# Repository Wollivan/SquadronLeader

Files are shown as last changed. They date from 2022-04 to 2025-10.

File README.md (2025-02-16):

###### visit [Squadron Leader Website](https://squadronleader.wollivan.dev)

###### visit [Squadron Leader subreddit](https://www.reddit.com/r/SquadronLeader/)

###### visit [Board Game Geek page](https://boardgamegeek.com/boardgame/362713/squadron-leader)

# Squadron Leader

#### The 3D printed, open source, aerial combat game you can fit in your pocket!

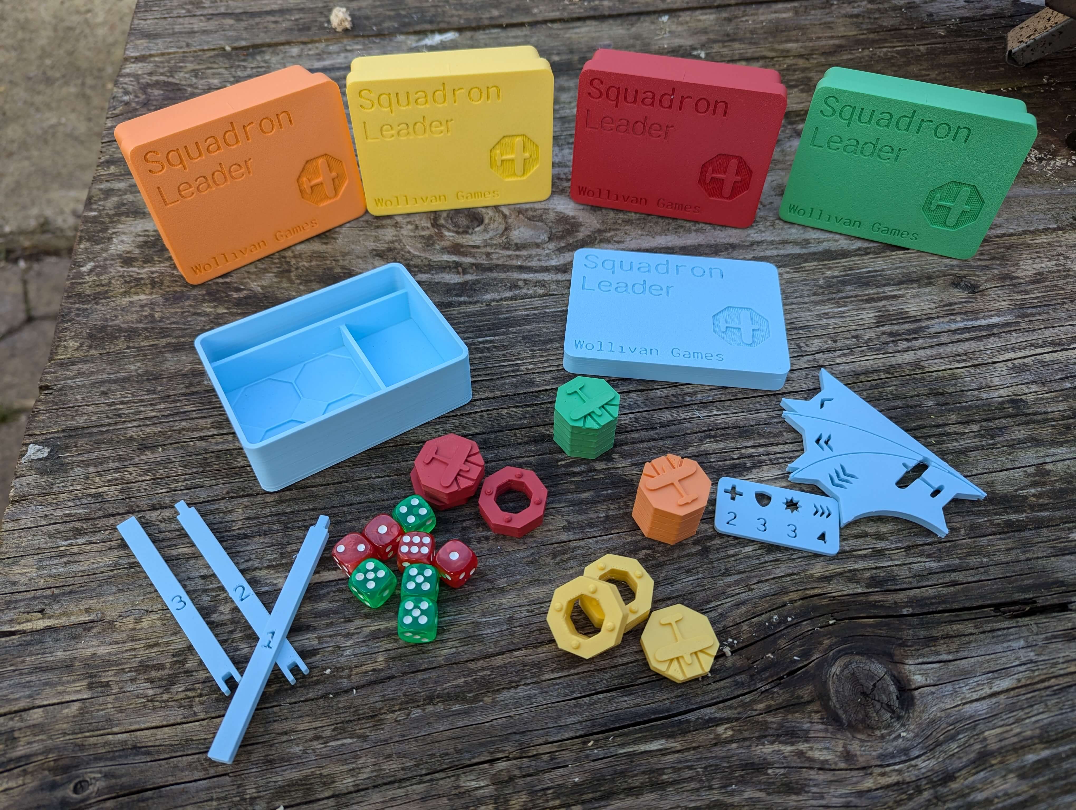
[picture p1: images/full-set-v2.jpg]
Squadron Leader Full Set


Squadron Leader is a fast-pace World War 1 (loosely) themed aerial combat game that is easy to learn and quick to play, with multifaceted strategy built-in that can be enjoyed by all ages!

The modular nature of the rules allows for players to customise their game and add entirely new layers of strategy.

We encourage the use of house rules, and if you think your rule improves the game, make a suggestion on <a href="https://github.com/Wollivan/SquadronLeader" target="_blank">GitHub</a>!

Tin art by Robert Linneman after the original Squadron Leader tobacco tin.

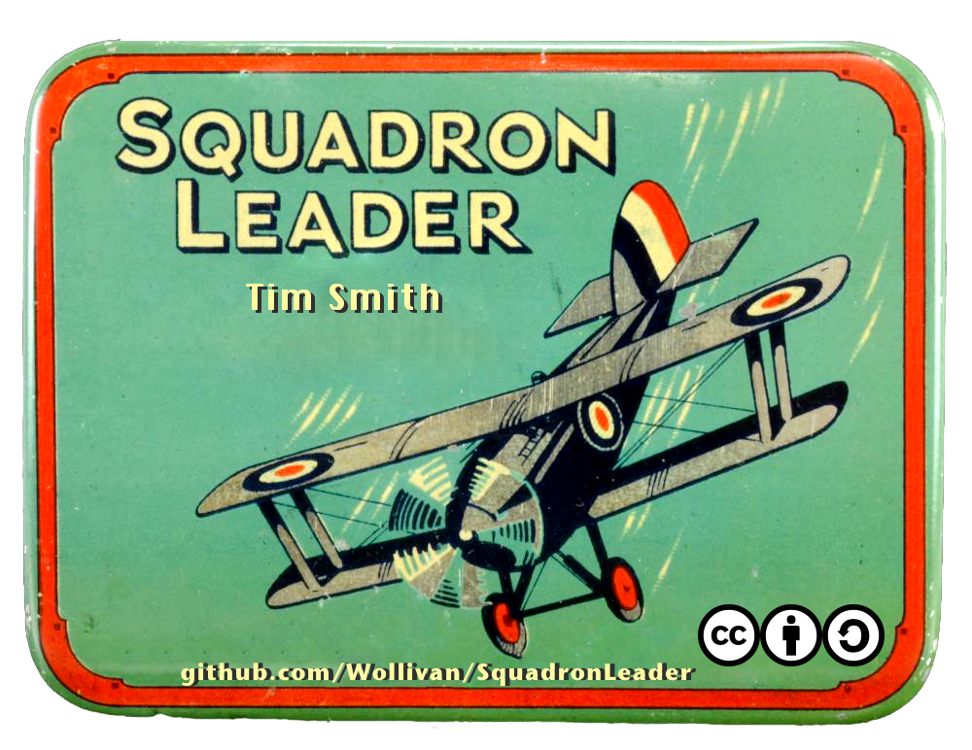
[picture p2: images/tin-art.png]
Squadron Leader Tin Art


### Learn the Game

- [How to Play](https://squadronleader.wollivan.dev/rules)
- [Advanced Manoeuvres](https://squadronleader.wollivan.dev/rules/advanced-manoeuvres)
- <a href="https://planes.wollivan.dev/" target="_blank">Plane Stat Tracker</a>

### Get Involved

- [Buy a copy](https://squadronleader.wollivan.dev/buy-a-copy)
- [Make your own copy](https://squadronleader.wollivan.dev/make-a-copy)
- [Make a change to the Project on GitHub](https://github.com/Wollivan/SquadronLeader)

**Note from the creator:**
This project is made possible only through the continued support of <a href="https://squadronleader.wollivan.dev/thanks" target="_blank">so many incredible people</a>, and for that I will be eternily grateful.
If you're viewing this on the website and want to see all the incredible work from the amazing people making this game better, check out the <a href="https://github.com/Wollivan/SquadronLeader/issues?q=is%3Aissue" target="_blank">issues</a>, <a href="https://github.com/Wollivan/SquadronLeader/pulls?q=is%3Apr" target="_blank">pull requests</a> and <a href="https://github.com/Wollivan/SquadronLeader/discussions" target="_blank">discussions</a> on GitHub.

## License

[Squadron Leader](https://github.com/Wollivan/SquadronLeader) by [Tim Smith](https://github.com/Wollivan) is licensed under [Attribution-ShareAlike 4.0 International](http://creativecommons.org/licenses/by-sa/4.0/?ref=chooser-v1)



CC BY-SA 4.0
Attribution-ShareAlike 4.0 International
This license requires that reusers give credit to the creator. It allows reusers to distribute, remix, adapt, and build upon the material in any medium or format, even for commercial purposes. If others remix, adapt, or build upon the material, they must license the modified material under identical terms.

BY: Credit must be given to the creator.

SA: Adaptations must be shared under the same terms.

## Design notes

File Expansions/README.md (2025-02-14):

# Expansions

There is a growing list of expansions that add additional pieces to the core game.

## X-Wing: The Miniatures Game Compatibility

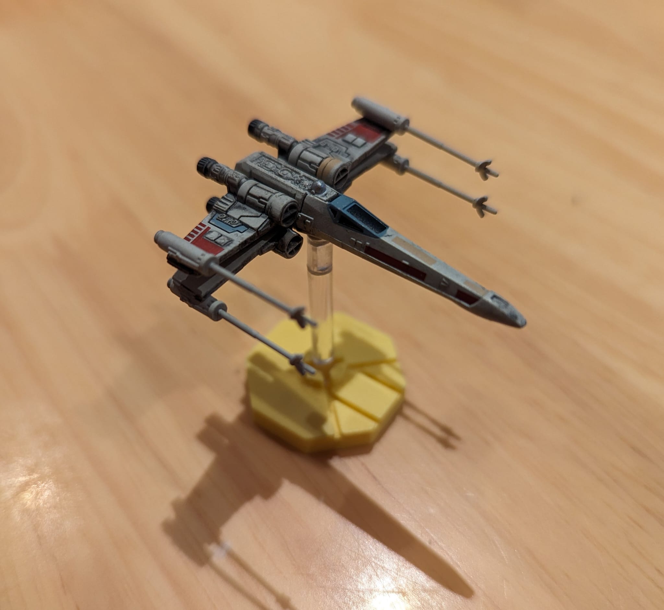
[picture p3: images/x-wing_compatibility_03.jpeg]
x-wing-assets


The force is strong with this one...

Use your X-Wing TMG collection to play Squadron Leader is a galaxy far far away!

<a href="https://squadronleader.wollivan.dev/expansions/x-wing-compatibility" class="button">Check it out!</a>

## Bomber & Balloons

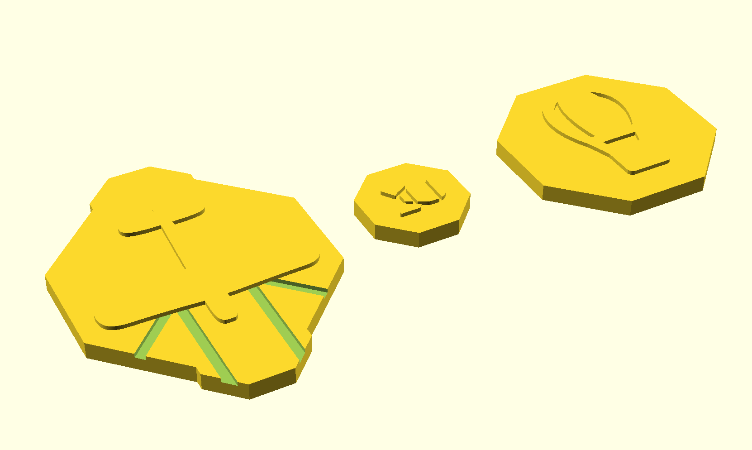
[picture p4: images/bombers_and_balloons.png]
bombers-and-balloons-assets


Bigger. Tougher. A fair bit slower.

<a href="https://squadronleader.wollivan.dev/expansions/bombers-balloons" class="button">Check it out!</a>

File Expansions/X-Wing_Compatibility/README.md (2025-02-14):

# X-Wing: The Miniatures Game Compatibility

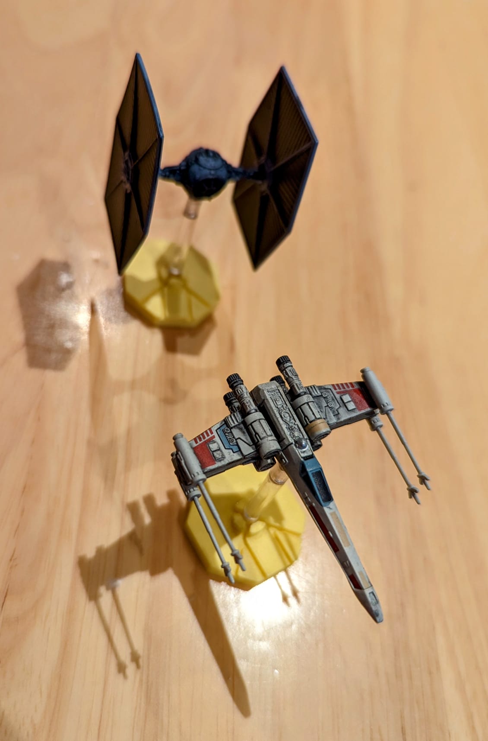
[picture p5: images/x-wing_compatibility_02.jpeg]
x-wing-assets


It's no secret that Squadron Leader was partially inspired by X-Wing TMG, so it stands to reason that there should be a way to use pieces from that amazing game to Sqquadron Leader.

Now you can with this new expansion!

There is a token for small bases using the 3mm peg, and large bases using the bomber token and space for the 6mm peg.

## Download Assets

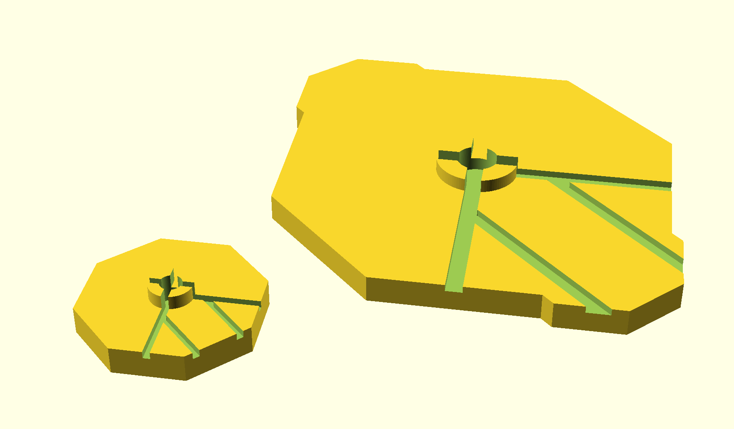
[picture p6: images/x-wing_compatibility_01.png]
x-wing-assets


Included:

- plane_xwing_tmg.stl
- plane_xwing_tmg_large.stl

<a href="https://github.com/Wollivan/SquadronLeader/tree/main/Expansions/X-Wing_Compatibility/STLs" class="button">Get the files</a>

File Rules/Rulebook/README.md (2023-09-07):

# Printable Rulebook for Squadron Leader

This page can be found at [sl-rulebook.wollivan.dev](https://sl-rulebook.wollivan.dev), or run locally.
It will give you a quick referece rules PDF to print out.

The reason there isn't a PDF saved here, is because the rules may change, and it saves whoever makes the change from having to regenerate the PDF.

Originally the rulebook site was run from a separate repo, but that felt wrong, so here it is to go with the rest of the Open Source goodness that is Squadron Leader.

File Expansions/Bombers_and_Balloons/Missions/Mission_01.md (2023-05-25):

# Mission 01 - The Errant Balloons

There are an unusual amount of Balloons in the area, I wonder if anyone is going to do anything about it!

## Game Piece Requirements

This misson requires:

- 3 Balloons
- 4 Planes

## Set up

One player will take all the Balloons and place them anywhere at least 1 range away from the edge of the play area.

Each player must place their tokens touching opposite sides of the play area to one another.
They start with 2 Planes each.

The player who placed the Balloons has an infinite supply of Planes. Every time one of their Planes are knocked out, wait 1 full round, then place the Plane back on the board anywhere along the edge the player originally started from.

## Objectives

The player who placed the Balloons must defend them at all costs!

The other player must destroy them... at any cost!

To destroy the Ballon, the player must attack them during the Attack Stage, and needs to make an attack with 2 hits.
A single hit on two consecutive turns won't cut it, it must be a double hit!

## Victory Requirements

The player who placed the Balloons wins if they destroy all enemy Planes.

The attacking player wins if they destroy all the Balloosn.

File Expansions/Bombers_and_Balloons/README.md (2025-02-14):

# Bombers & Balloons

bombers-and-balloons-assets

This expansion adds 2 new game pieces to the game, and you guessed them:

Bombers and Balloons!
(and a surprise third, the Bomb token)

## Bombers

Bombers use a larger token that can be found <a href="https://github.com/Wollivan/SquadronLeader/tree/main/Expansions/BombersAndBallons/STLs" target="_blank">here</a>. They use the same manoeuvre template as the other planes, making use of the extranious pieces at the front and back of the token.

Here are the special rules for the Bomber token:

- Instead of having the stats 4,3,3,2 to assign, they have 4,4,2,2
- Bombers are slower so their  must be 2
- Bombers may only spend 1 altitude when they dive
- The bomber can fire in a 360° arc if the enemy is within range 1-2 (forward arc is range 3)
- The bomber can "Drop Bombs"

### Dropping Bombs

At the end on their manoeuvre, the bomber may Drop a Bomb, by placing the bomb token at the other end of the template they just used for their manoeuvre.

Excluding the turn it was dropped, if any player is within range 1 of the bomb at the end the round, they roll 4  dice and takes 1 damage on all 4-6 results.

## Balloons

Balloons are a stationary object placed in the playing area before the game starts. Balloons are placed **before** planes.

During the game, if a player comes within range 1 of the balloon, that player immediatley rolls 4  dice and takes 1 damage on all 4-6 results.

It is up to the players to decide how many balloons each player may place before the game starts. They can be placed in any area the player chooses. Players take turns placing Balloons.

## Missions

There are some scenarios for players to use with their Bombers and balloons, and they can be found here:

<a href="https://squadronleader.wollivan.dev/expansions/bombers-balloons/mission-01.md" class="button">Mission 01 - The Errant Balloons</a>

<a href="https://squadronleader.wollivan.dev/expansions/bombers-balloons/mission-02.md" class="button">Mission 02 - The Bombers Escape</a>

## Cover

Bombers and Balloons both have one major thing in common... they are big!

If an attacker is shooting a target (any kind of target) they **roll 1 less dice** and **may not re-roll** any of their dice for this attack.

## Download Assets

Included:

- bomber.stl
- bomb.stl
- balloon.stl

<a href="https://github.com/Wollivan/SquadronLeader/tree/main/Expansions/Bombers_and_Balloons/STLs" class="button">Get the files</a>

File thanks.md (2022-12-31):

# Thank yous

First and most important thank you to <a href="https://twitter.com/HarryTheGM?t=-lbRdIOqqLyfzbsDPnInbA&s=09" target="_blank">Harry the GM</a> for inspiring me to make a game in the first place.

Playtesters. Without your help, this game would suck.

- Becky
- Bekah
- Ben
- Chris
- Dan
- Danny
- Harry
- John
- Josh
- Lydia
- Martin
- Matti
- Moses
- Patrick
- Priyatham

and a special thanks for their genius in coming up with a new barrel roll rule:

- Dylon
- Kirk
- Lila

a major thank you for their immediate help on release with getting the rules more readable, adding the Hex Grid rules and the d6 rules:

- Pelle

a thank you on the visual learners:

- Adam

for the awesome stat tracking designs:

- Greg

and for the important fix of making sure the game met Open Source requirements:

- avamk
- penyuan
- TechnologyClassroom

and for their awesome contributions to making an awesome printable box:

- Amnos
- Flo

and for STICKERS:

- mevdev

## Inspiration

This game was inspired by X-Wing TMG and Wings of War. The motivation for creating Squadron Leader was not as a replacement to either of these, rather as a alternative, when time, space and people who don't want to learn complex games are a factor when trying to get your gaming fix.

gameplay-gif

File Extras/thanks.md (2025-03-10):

# Thank yous

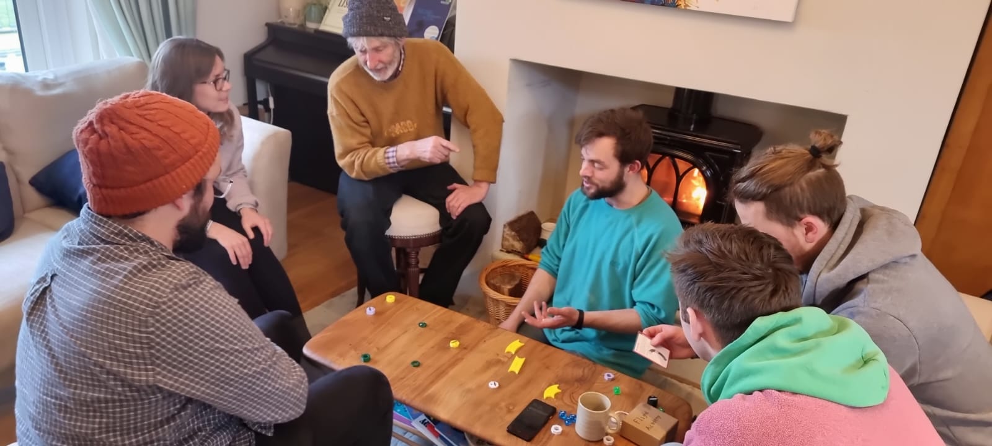
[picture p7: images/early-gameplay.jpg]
gameplay


First and most important thank you to <a href="https://twitter.com/HarryTheGM?t=-lbRdIOqqLyfzbsDPnInbA&s=09" target="_blank">Harry the GM</a> for inspiring me to make a game in the first place.

Playtesters. Without your help, this game would suck.

- Becky
- Bekah
- Ben
- Chris
- Dan
- Danny
- Harry
- John
- Josh
- Lydia
- Martin
- Matti
- Moses
- Patrick
- Priyatham

and a special thanks for their genius in coming up with the original barrel roll rule:

- Dylon
- Kirk
- Lila

a major thank you for their immediate help on release with getting the rules more readable, adding the Hex Grid rules and the d6 rules:

- Pelle

a thank you on the visual learners:

- Adam

for the awesome stat tracking designs, still available within the v1 folders:

- Greg

and for the important fix of making sure the game met Open Source requirements:

- avamk
- penyuan
- TechnologyClassroom

and for their awesome contributions to making an awesome printable box:

- Amnos
- Flo

and for STICKERS:

- mevdev

and for the Push the Envelope rules:

- asmialek

and for teaching me that all these special manoeuvres have names

- Ben

and for finding Split S so that what the rules do in game match what real life planes can do!

- Josh

and for a lot of inspiration on the Bimber expansion

- u/ReasonablyCreamy

## Future features

- Coop objectives & campaigns
- Large scale battle rules (10+ ships per team)
- Assets & instructions for playmats
- Printable assets for 3D models on blank bases
- More accessible components for less able players

## Inspiration

This game was inspired by X-Wing TMG and Wings of War. The motivation for creating Squadron Leader was not as a replacement to either of these, rather as a alternative, when time, space and people who don't want to learn complex games are a factor when trying to get your gaming fix.

How it started:

unboxing

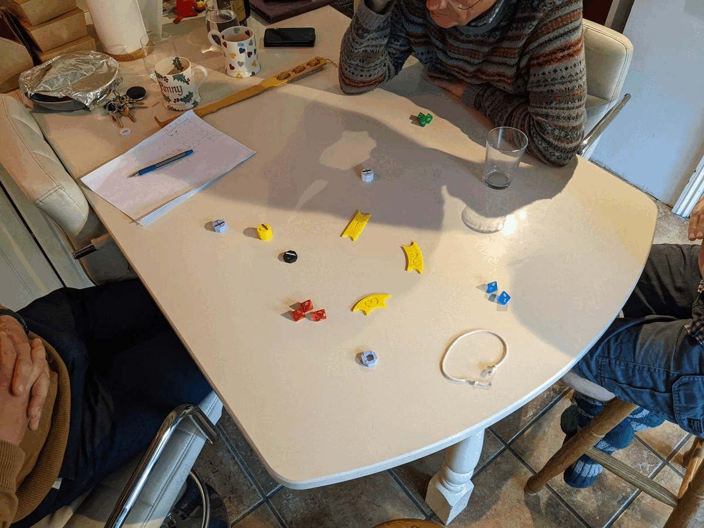
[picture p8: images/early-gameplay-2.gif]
gameplay-gif


How it's going:

unboxing

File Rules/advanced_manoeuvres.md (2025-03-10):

# Advanced Manoeuvres

For players already familiar with the core rules or those seeking to become world-famous fighter pilots, the following advanced manoeuvres provide additional tactical options:

**Note:** Manoeuvres that cost altitude cannot be performed in the same round that the player has gained altitude.

## Barrel Roll

This manoeuvre seperates the timid from the bold!

**Cost:** This is the only manoeuvre you can do this round

**Action:** Perfom a 3 cost manoeuvre but don't rotate your token afterwards

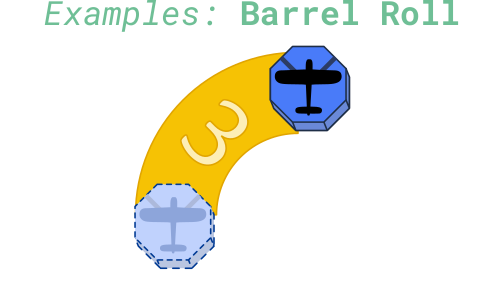
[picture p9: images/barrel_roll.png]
barrel_roll_diagram


## Dive Bomb

Reward hyper-aggresive tactics with this risky manoeuvre!

**Requirement:** Perform an attack against a plane within range 1 that has less altitude

**Cost:** Reduce altitude to match defender

**Action:** Roll a d6:

- Result of 3-6: Deal one damage.
- Result of 1-2: Take one damage.

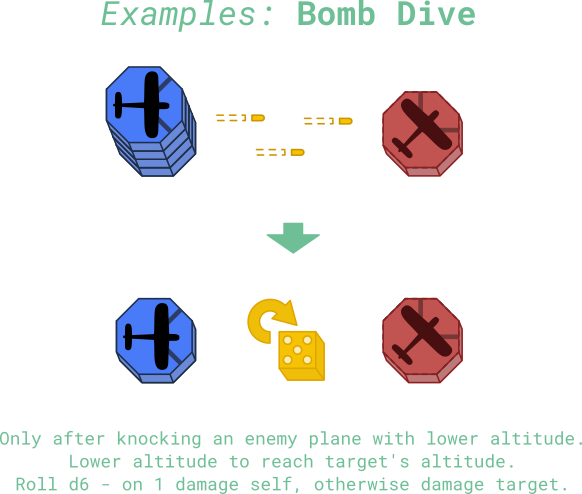
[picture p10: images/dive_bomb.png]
dive_bomb_diagram


Not to be confused with Divebomb, the homicidal Decepticon.

## Immelmann

Few pilots ever pull this manoeuvre off.

**Requirement:** Eliminate opponent while you have no altitude tokens

**Action:** Gain 4 altitude, perform a straight manoeuvre and rotate plane 180°

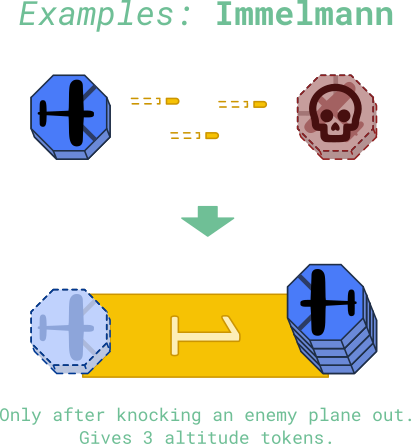
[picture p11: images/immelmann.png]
immelmann_diagram


## Push the Envelope

This manoeuvre rewards daring pilots who are willing to test the limits of the aircraft by going faster and higher than it should be possible!

A player may push the envelope during the manoeuvre stage and roll a d6:

**Requirement:** Execute during Manoeuvre stage, once per round

**Action:** Roll a d6:

- Result of 5-6: Gain 1  this round OR 1 extra altitude.
- Result of 1-4: Take one damage.

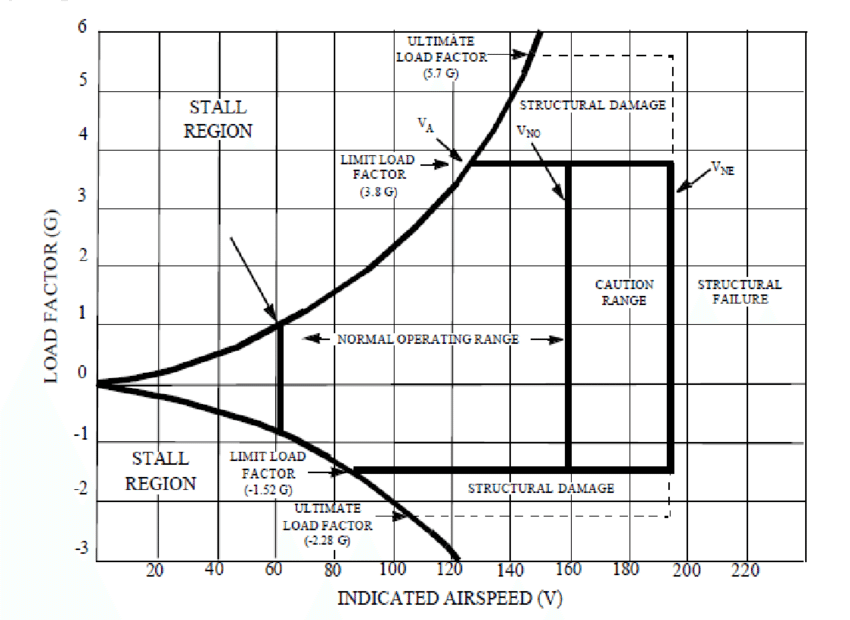
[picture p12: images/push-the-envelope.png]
push-the-envelope


### More Info

All the manoeuvres are informed by real life actual plane stuff!

- [Barrel Roll](https://en.wikipedia.org/wiki/Barrel_roll): "A barrel roll is an aerial manoeuvre in which an airplane makes a complete rotation on both its longitudinal and lateral axes, causing it to follow a helical path, approximately maintaining its original direction."

- [Dive Bomb](https://en.wikipedia.org/wiki/Dive_bomber): "A dive bomber is a bomber aircraft that dives directly at its targets in order to provide greater accuracy for the bomb it drops. Diving towards the target simplifies the bomb's trajectory and allows the pilot to keep visual contact throughout the bomb run."

- [Immelmann](https://en.m.wikipedia.org/wiki/Immelmann_turn): "In modern aerobatics, an Immelmann turn (also known as a roll-off-the-top, or simply an Immelmann) is an aerobatic manoeuvre that results in level flight in the opposite direction at a higher altitude."

- [Push the Envelope](https://en.wikipedia.org/wiki/Flight_envelope#%22Pushing_the_envelope%22): "The flight envelope is a graph visualizing the capabilities of the aircraft in terms of min-max speeds and the altitude at which it can safely fly. The envelope itself is of course defined by various parameters and there is absolutely no way of simulating that in a board game. But, there is a term "Pushing the envelope", which means that the pilot tries to go over the speed or altitude defined by the flight envelope while risking the integrity of the aircraft (or causing the plane to stall)."

- [Split S](https://en.m.wikipedia.org/wiki/Split_S): "To execute a split S, the pilot half-rolls their aircraft inverted and executes a descending half-loop, resulting in level flight in the opposite direction at a lower altitude."

### Printable Rulebook

No not that sort of printing, _actual_ printing with paper and everything!

If you want a quick reference to the rules that fits in the printable (3D this time) box, then you can donwload the PDF from [here](https://sl-rulebook.wollivan.dev), or go to [the folder that website comes from](https://github.com/Wollivan/SquadronLeader/tree/main/Rules/Rulebook) if you want to make a change.

This bifold book contains the basic rules and a quick reference to the advanced manoeuvres.

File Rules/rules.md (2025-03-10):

# Rules

**Objective:** Be the last plane in the air by reducing your opponents' Health to zero.

## Setup:

Each player needs:

- 1 plane token
- 4 altitude tokens

Shared items:

- 1 move template
- 1 range ruler
- 4 Red d6 for Attack dice
- 4 Green d6 for Defense dice

### Playing Area:

The playing area can be any size, typically the entire table. For a consistent size, try 3 lengths of the range ruler.

### Starting Assignments:

At the beginning of the game, each player assigns values from 4, 3, 3, 2 to the following attributes:

 - Health

 - Defense

 - Attack

 - Manoeuvrability

Suggested starting setup for new players:

 - 3

 - 3

 - 2

 - 4

Use the <a href="https://planes.wollivan.dev/" target="_blank">online stat tracker</a>, or print the v1 stat wheels (requires a v1 box).

### Determining First Player:

The player who last saw a plane in real life goes first.

### Placing the Planes:

Each player places their plane on the playing area in turn. The plane should be placed within range 1 of the edge of the playing area, and no closer than the range ruler's length to another player.

### Game Rounds:

Each round consists of two stages: the Manoeuvre Stage and the Attack Stage.

The player who starts the round moves and attacks first. In the next round, the player to their left will start the round.

## Manoeuvre Stage:

- To move, place the manoeuvre template at the front of the plane token and move the plane to the other end of the template.
- Players can use manoeuvre templates up to the value of their  score. For example, a player with  4 can execute 2 straight manoeuvres and 1 bank manoeuvre (1 + 1 + 2).
- Each player must complete at least one manoeuvre each round; otherwise, their plane will stall and plummet to the ground.
- If any part of a plane token goes off the board at the end of a manoeuvre, that plane is destroyed.

### Altitude:

Take advantage of the sky's vastness!

- At the start of the game, each player begins with 0 altitude tokens.
- Once per round during their manoeuvre stage, a player may spend 1  to Climb and add 1 altitude token beneath their plane.
- Players can gain a maximum of 1 altitude per round.
- If a player hasn't Climbed this round, they may Dive by removing any number of altitude tokens to gain an equal amount of  this round.
- The maximum allowed altitude is 4.

### Split S

This manoeuvre prevents a pilot from being stuck when they are being tailed by an opponent.

**Cost:** 4 altitude
**Action:** Turn 180° after manoeuvre

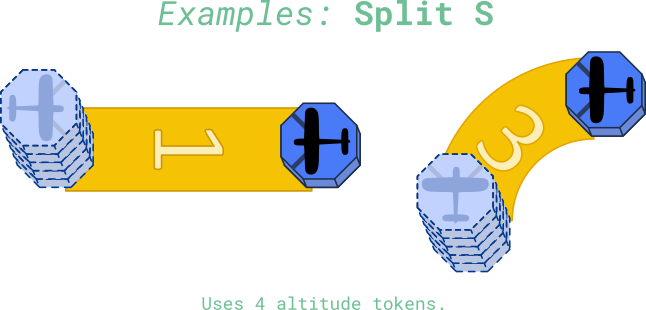
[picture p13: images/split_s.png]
split_s_diagram


Note: You can't Split S on the same turn as gaining altitude.

## Attack Stage:

- The attacker declares which enemy plane they will attack.
- A player can only attack if the enemy plane is within range.
  - Use the range ruler to ensure both planes are within the designated distance from each other.
- The defender must also be within the attacker's firing arc, indicated by the 90° lines on the front of the token.
- The attacking player rolls a number of  dice equal to their Attack value.
- The defending player rolls a number of  dice equal to their Defense value.
- Each value of 4-6 rolled on the  dice counts as a **hit** and deals 1 damage.
- Each value of 4-6 rolled on the  dice counts as a **dodge** and cancels out a hit.
- Rolling a 6 results in a **critical hit** or a **vital dodge**, counting as 2 hits or dodges respectively.
- The defender loses  equal to the uncanceled hits.

Example of the firing arc:
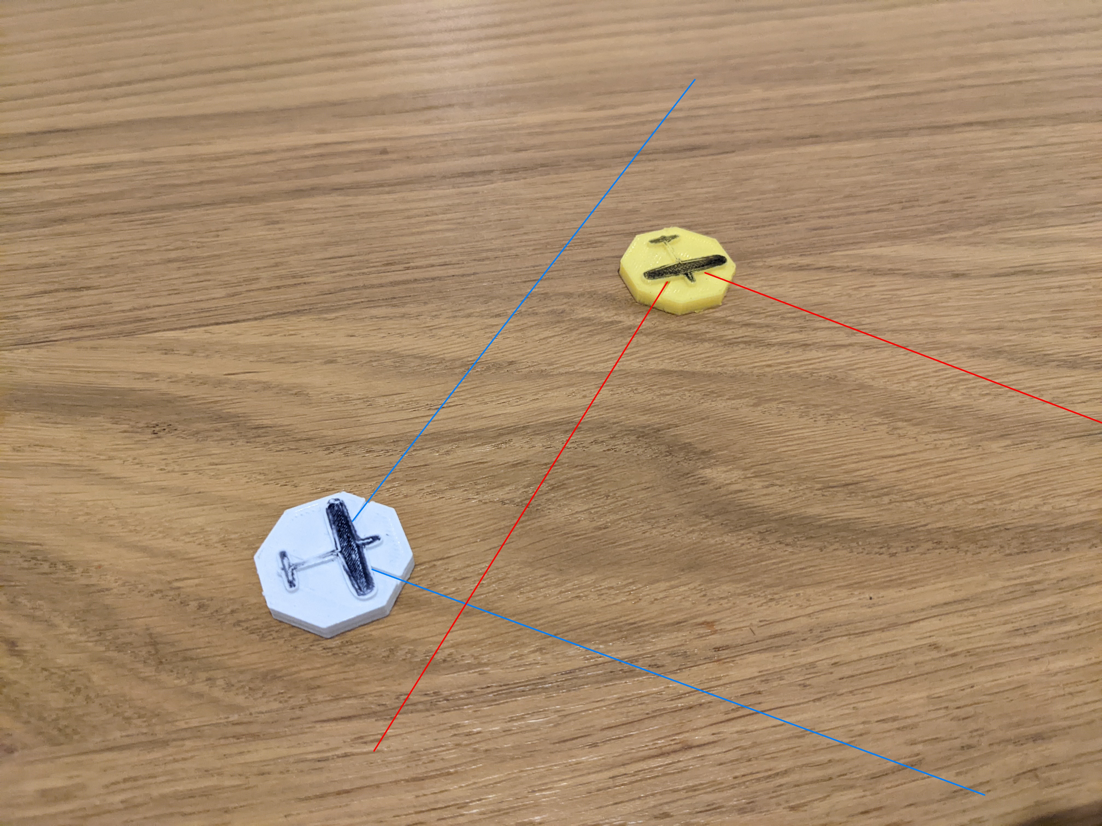
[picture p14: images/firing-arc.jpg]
firing-arc


### Attack/Defense Bonuses:

Bonuses allow rerolling of dice. The number of dice rolled is determined by the Attack/Defense stats.

- The defender may reroll 1 die if they are within range 3 of the attacker.
- The attacker may reroll 1 die if the defender is within range 1.
- If the defender is within the attacker's forward firing guides, the attacker may reroll 1 die.
- An attacker or defender with higher altitude may reroll 1 die.
- When you destroy an enemy plane, you may reroll 1 die during your next attack.

## Next Round:

After the last player who can attack finishes their turn, a new round begins with the next starting player.

### Advanced Manoeuvres:

Explore the [advanced manoeuvres](https://squadronleader.wollivan.dev/rules/advanced-manoeuvres) and test your skills to rule the air!

### Printable Rulebook

No not that sort of printing, _actual_ printing with paper and everything!

If you want a quick reference to the rules that fits in the printable (3D this time) box, then you can donwload the PDF from [here](https://sl-rulebook.wollivan.dev), or go to [the folder that website comes from](https://github.com/Wollivan/SquadronLeader/tree/main/Rules/Rulebook) if you want to make a change.

This bifold book contains the basic rules and a quick reference to the advanced manoeuvres.

**Enough chatter, it's time to take to the skies!**

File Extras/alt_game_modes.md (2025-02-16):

# Alternative Game modes

## Team game

You can change the feel of the game greatly by flying with a wingman. The strategy of how you fly together is totally up to you. Here are the additional rules for playing in teams:

- Teammates should sit next to one another.
- The playing order is determined by teams, rather than players, so within your team you decide who moves first, and once the entire team has moved, the other team goes. This is the same principle for attacking.

## Quick game

There are a few ways to make the game shorter:

- Have everyone start with a max of 2 Health.
- Designate a smaller playing area.
- Allow players to gain more than 1 altitude per round.

Feel free to experiment with the starting numbers, the original 4,3,3,2 is a guideline for balanced games, so going higher will change the game. As long as each player has the same choices it SHOULD be fair.

## Hex Grid Mode (for players without a 3D printer)

The game can be played on a hex grid. That removes the need for manoeuvre templates and range rulers. All rules are the same as without a grid, except for what is described in this section.

Any battlemat with a hex grid can be used. Planes set up in hexes along each player's edge of the mat. There can only ever be one plane per hex, and planes can never end a manoeuvre in the same hex as another plane. A plane always face one of the six sides of its hex.

Instead of using the manoeuvre templates there are three possible manoeuvres on a hex grid that are used instead:

- 1 (Cost 1) Move 2 hexes forward.
- 2 (Cost 2) Move 1 hex forward, then turn left or right 60 degrees, then move 1 hex forward in the new direction.
- 3 (Cost 3) Turn 60 degrees, then move 1 hex forward, then turn another 60 degrees in the same direction as the first turn

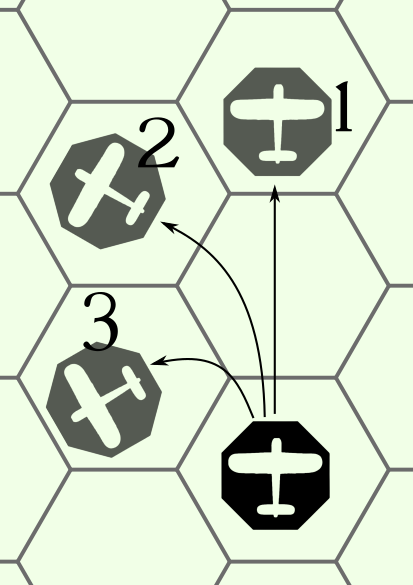
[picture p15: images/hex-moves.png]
hex_moves


Attacks are up to range 3. Count range in hexes, not including the hex occupied by the attacking plane, but including the attacked plane. The firing arc of a plane is a cone in front of it, starting with the single hex in front, then the 3 hexes in front of that, then the 5 beyond those.

The hexes immediately in front of the firing plane corresponds to the closest section of the range ruler for the purpose of attack bonuses. Hexes at range 3 corresponds to the furthest section of the range ruler.

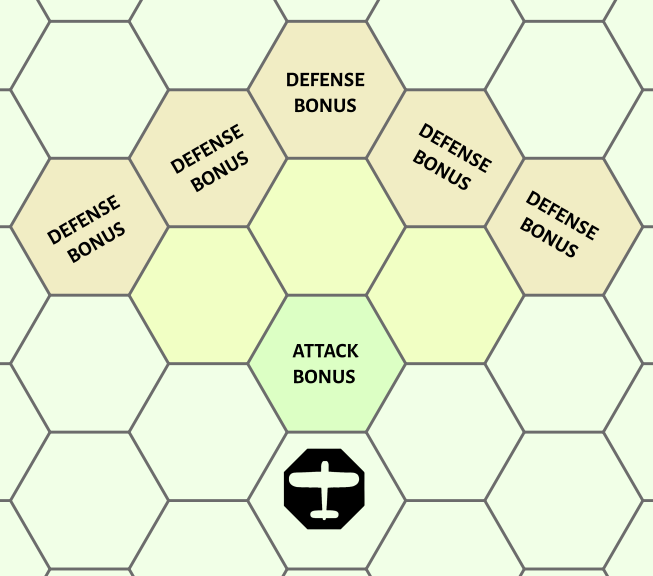
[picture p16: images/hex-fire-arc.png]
hex_fire_arc


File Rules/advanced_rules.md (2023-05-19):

# Advanced Rules

These rules are for players already familiar with the core rules, or those who want to dive right in and become world famous fighter pilots!

## Split S

This rule prevents a pilot from being stuck when they are being tailed by an opponent.

- The Split S costs 4 altitude to execute.
- Turn the plane token 180° at the end of the manoeuvre.
- Players cannot perform a Split S and gain altitude in the same round.

split-s

You can read more about the Split S manoeuvre here:

<a href="https://en.m.wikipedia.org/wiki/Split_S" target="_blank" class="button">Split S Wiki</a>

Here is an excerpt:

"To execute a split S, the pilot half-rolls their aircraft inverted and executes a descending half-loop, resulting in level flight in the opposite direction at a lower altitude."

## Immelmann

This rule rewards aggressive tactics.

- This free manoeuvre that can only be performed immediatley after reducing another opponent's Health to 0.
- Do the following actions in order:
  - Gain 3 altitude tokens
  - Execute a straight
  - Turn your plane 180° (facing the opposite direction to the way they were).

immelmann_with_text

You can read more about the Immelmann turn here:

<a href="https://en.m.wikipedia.org/wiki/Immelmann_turn" target="_blank" class="button">Immelmann Wiki</a>

Here is an excerpt:

"In modern aerobatics, an Immelmann turn (also known as a roll-off-the-top, or simply an Immelmann) is an aerobatic manoeuvre that results in level flight in the opposite direction at a higher altitude."

## Barrel Roll

This rule seperates the timid from the bold!

- During the manoeuvre phase a player may declare they are executing a Barrel Roll and execute either the 2 or 3 cost manoeuvre, but instead of orienting their plane along the new axis, their token will not rotate at all, and be traveling in the same direction.
- The manoeuvre cost is double the cost of whichever manoeuvre template the player is using (the straight now costs 2, the bank now costs 4).
- Players cannot perform a Barrel roll and gain altitude in the same round.

barrel_roll_with_text

You can read more about the Barrel roll manoeuvre here:

<a href="https://en.wikipedia.org/wiki/Barrel_roll" target="_blank" class="button">Barrel Roll Wiki</a>

Here is an excerpt:

"A barrel roll is an aerial manoeuvre in which an airplane makes a complete rotation on both its longitudinal and lateral axes, causing it to follow a helical path, approximately maintaining its original direction."

## Dive Bomb

After a players has attacked a plane within range 1 **and** they have more altitude than the defender, they may attempt to perform a dive bomb manoeuvre:

- Remove altitude tokens from the attacker until they have the same number as the defender
- The attacker rolls a d6:
  - On a 2-6 result the defender suffers 1 damage
  - On a 1 result the attacker suffers 1 damage

You can read more about the Dive Bomb manoeuvre here:

<a href="https://en.wikipedia.org/wiki/Dive_bomber" target="_blank" class="button">Immelmann Wiki</a>

Here is an excerpt:

"A dive bomber is a bomber aircraft that dives directly at its targets in order to provide greater accuracy for the bomb it drops. Diving towards the target simplifies the bomb's trajectory and allows the pilot to keep visual contact throughout the bomb run."

Not to be confused with the Divebomb, the homicidal Decepticon.

## Ace Pilot

Earn your wings and keep the action moving!

- When a pilot destroys another plane, they become the Ace.
- For as long as they are the Ace, that pilot may reroll 1 Attack dice and 1 Defense dice each round.
- There can only be one Ace in the sky at a time.

## Pushing the Envelope

This rule rewards daring pilots who are willing to test the limits of the aircraft by going faster and higher than it should be possible!

Any a player push the envelope and roll a d6:

- On a result of 5-6 they gain gain 1 extra Manoeuvrability for the turn.
- On a result of 1-4, they lose 1 Health.
- The pilot may only "Push the envelope" only once per turn.

The flight envelope is a graph visualizing the capabilities of the aircraft in terms of min-max speeds and the altitude at which it can safely fly. The envelope itself is of course defined by various parameters and there is absolutely no way of simulating that in a board game. But, there is a term "Pushing the envelope", which means that the pilot tries to go over the speed or altitude defined by the flight envelope while risking the integrity of the aircraft (or causing the plane to stall).

push-the-envelope

<a href="https://en.wikipedia.org/wiki/Flight_envelope#%22Pushing_the_envelope%22" target="_blank" class="button">Immelmann Wiki</a>

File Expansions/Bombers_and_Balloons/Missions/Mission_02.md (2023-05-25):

# Mission 02 - The Bombers Escape

Intel suggests there is a new Bomber being escorted to base. Rumours suggest it is the only prototype...

## Game Piece Requirements

This misson requires:

- 1 Bomber
- 4 Planes
- A play area that is at least 3 rangle rulers wide and long

## Set up

Each player must place their tokens touching opposite sides of the play area to one another.
They start with 2 Planes each.

One player will control the bomber. Its Stats are:

- Health - 4
- Defense - 4
- Attack - 2
- Manoeuvrability - 2

The Bomber has 3 bombs it may drop during the game.

## Objectives

The player who controls the Bomber must escort it from one end of the play area to the other.

The other player must destroy it!

The player who does not control the Bomber has an infinite supply of Planes. Every time one of their Planes are knocked out, wait 1 full round, then place the Plane back on any edge of the board excluding the edge they started from.

## Victory Requirements

The player who controls the Bomber wins if the Bomber reaches the other end of the play area.

The other player wins if they destroy the Bomber.

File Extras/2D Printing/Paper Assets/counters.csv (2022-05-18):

plane | plane-side | plane-nr | plane-background[style:fill]
 | A | I | lightskyblue
 | A | II | lightskyblue
 | A | III | lightskyblue
 | A | IV | lightskyblue
 | A | V | lightskyblue
 | A | VI | lightskyblue
 | A | VII | lightskyblue
 | A | VIII | lightskyblue
 | A | IX | lightskyblue
 | A | X | lightskyblue
 | B | I | khaki
 | B | II | khaki
 | B | III | khaki
 | B | IV | khaki
 | B | V | khaki
 | B | VI | khaki
 | B | VII | khaki
 | B | VIII | khaki
 | B | IX | khaki
 | B | X | khaki
altitude | altitude-n
14 | 1
13 | 2
12 | 3
11 | 4
health | health-n
10 | 1
10 | 2
10 | 3

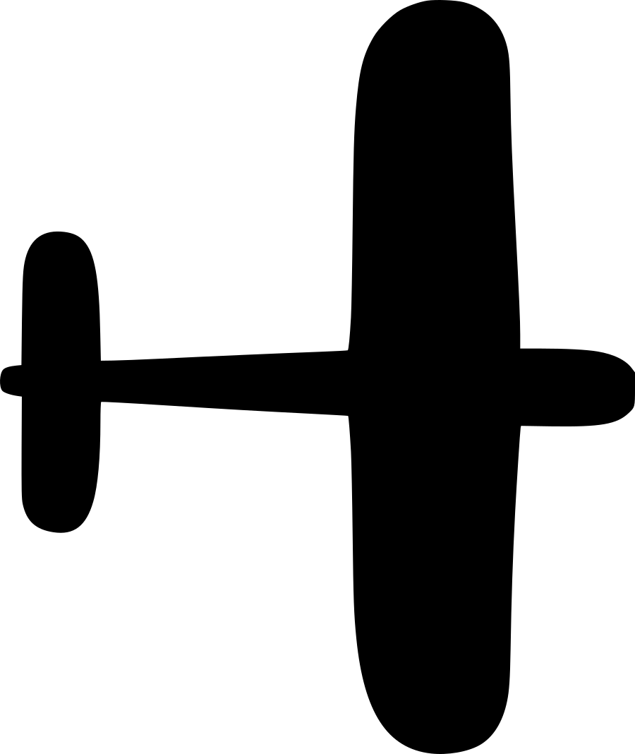
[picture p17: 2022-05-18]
Extras/2D Printing/Paper Assets/plane-model.png

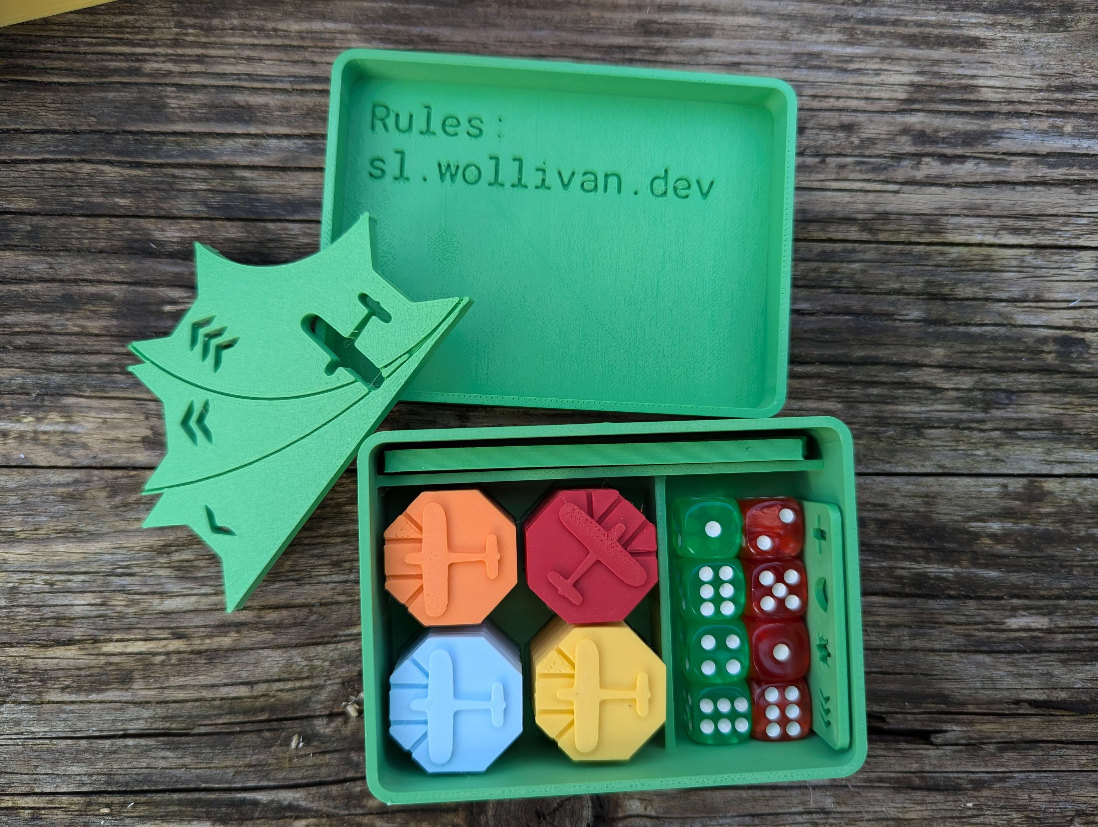
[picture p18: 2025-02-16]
images/full-set-v2-green.jpg

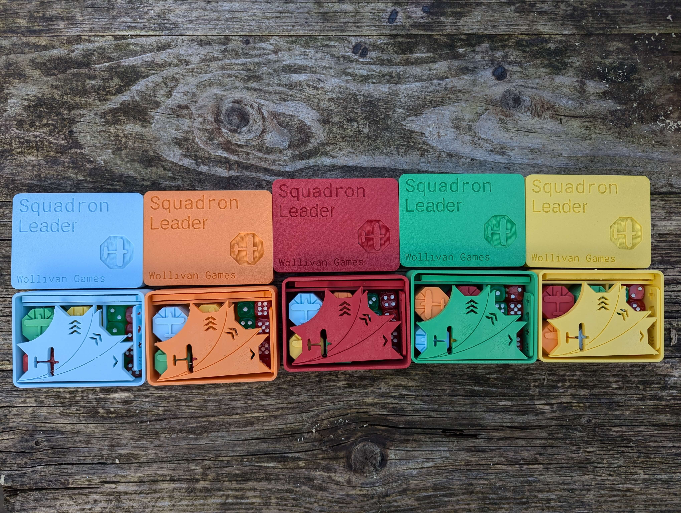
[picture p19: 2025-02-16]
images/full-set-v2-lined-up-02.jpg

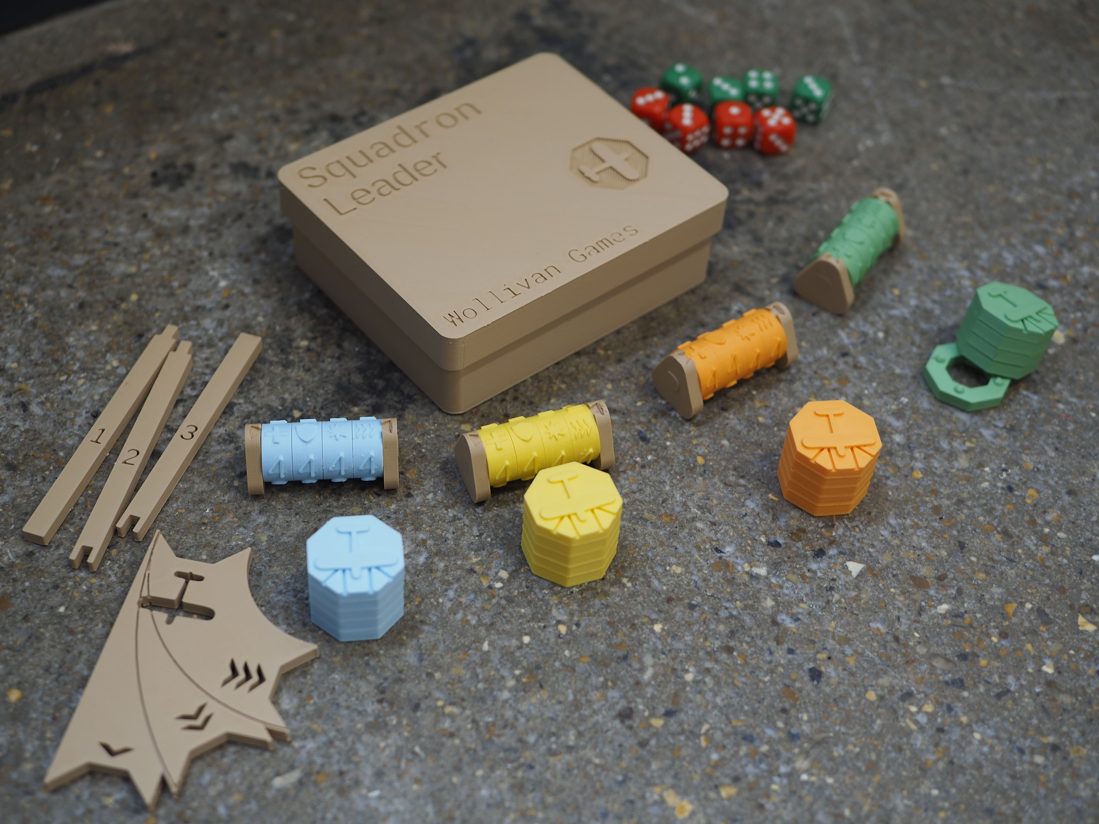
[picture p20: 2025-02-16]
images/full-set-v1.jpeg

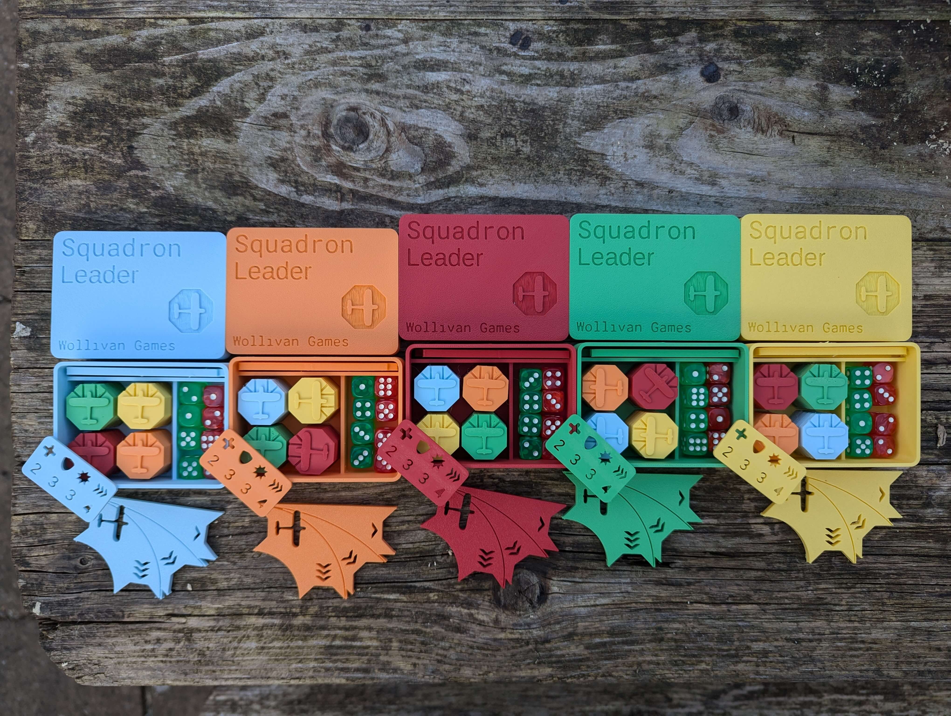
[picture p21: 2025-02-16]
images/full-set-v2-lined-up-01.jpg

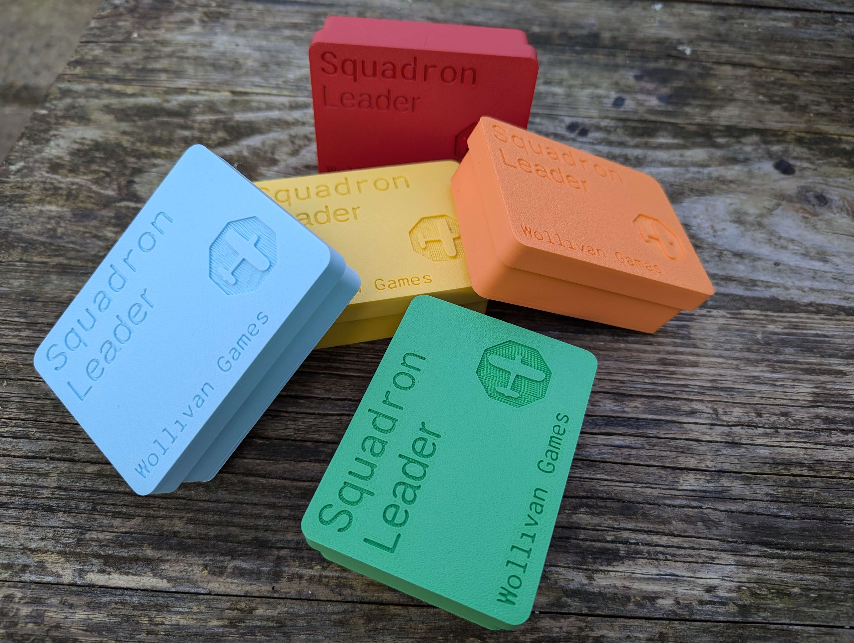
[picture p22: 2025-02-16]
images/full-set-v2-pile.jpg

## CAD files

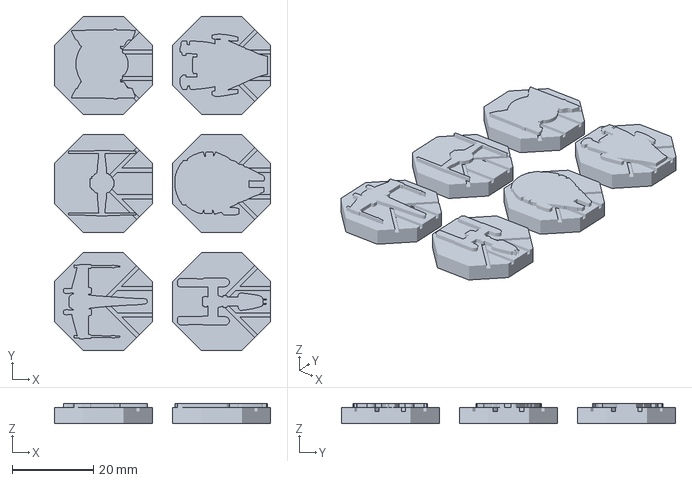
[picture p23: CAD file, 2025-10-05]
3DPrinting/OpenSCAD/expansions/star-wars.3mf
53.0 x 82.0 x 5.00 mm

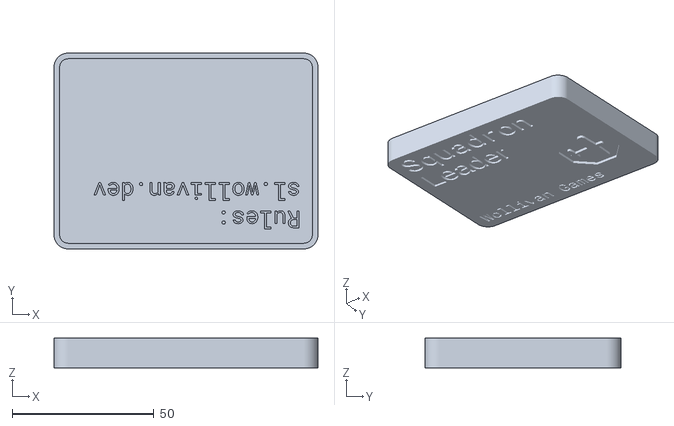
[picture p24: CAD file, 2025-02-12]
3DPrinting/STLs/individual_models/boxv2_lid.stl
93.0 x 69.0 x 10.4

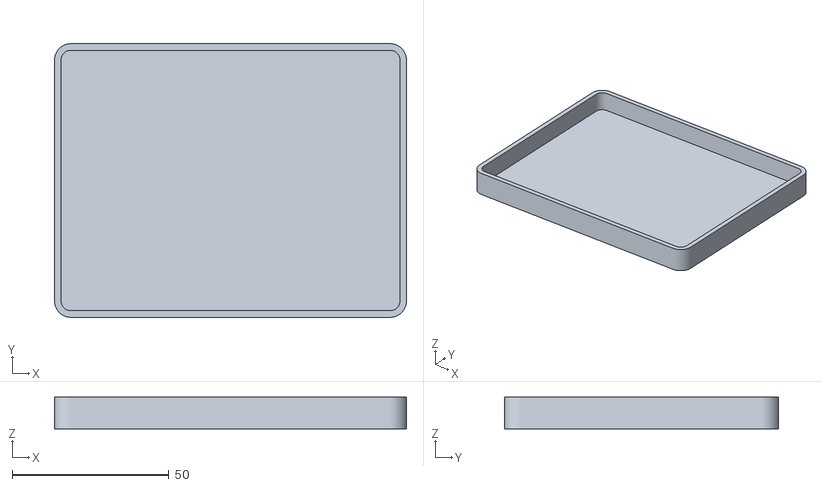
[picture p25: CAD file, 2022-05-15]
3DPrinting/STLs/individual_models/fancy_box/box_top_fancy_part_1.stl
112.1 x 87.2 x 10.2

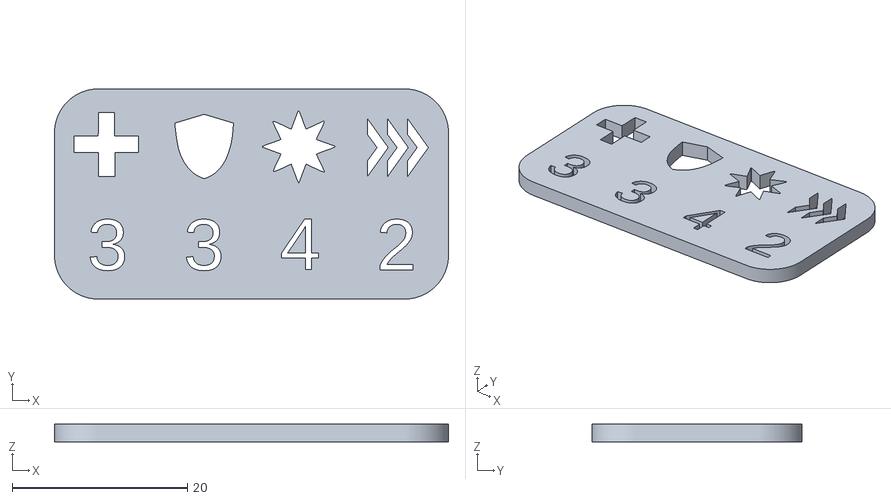
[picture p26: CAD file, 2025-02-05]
3DPrinting/STLs/individual_models/stat_board_number_variations/3342.stl
45.0 x 24.0 x 2.00

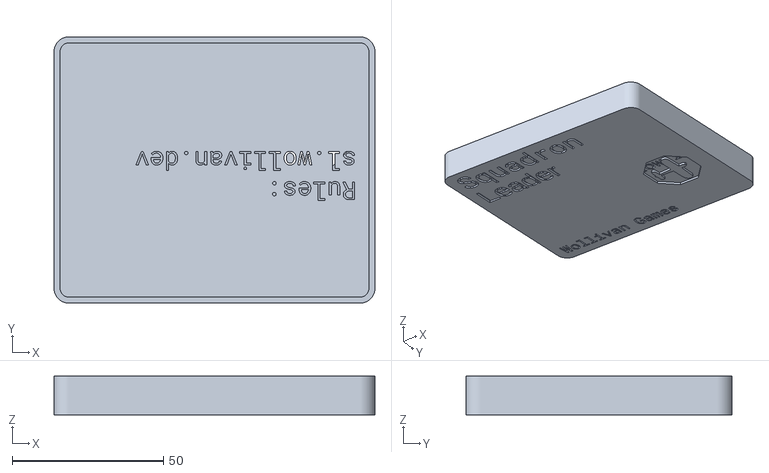
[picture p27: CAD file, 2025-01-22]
3DPrinting/STLs/individual_models/v1/box_top.stl
106.0 x 88.0 x 12.8

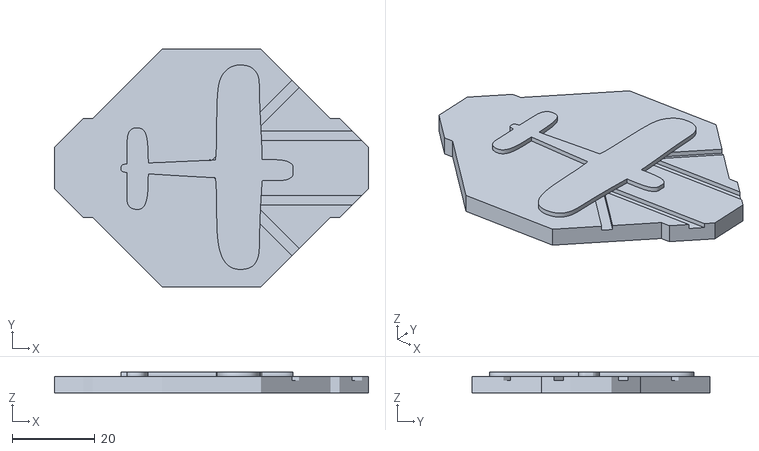
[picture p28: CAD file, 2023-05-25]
Expansions/Bombers_and_Balloons/STLs/bomber.stl
76.0 x 57.7 x 5.00

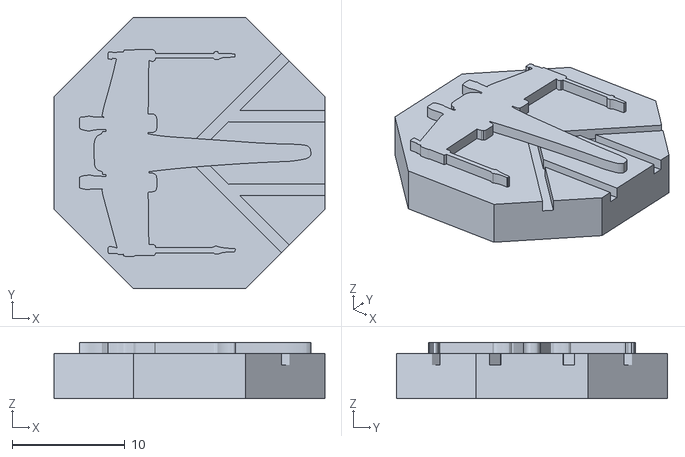
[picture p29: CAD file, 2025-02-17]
Expansions/Star_Wars/x-wing.stl
24.0 x 24.0 x 5.00

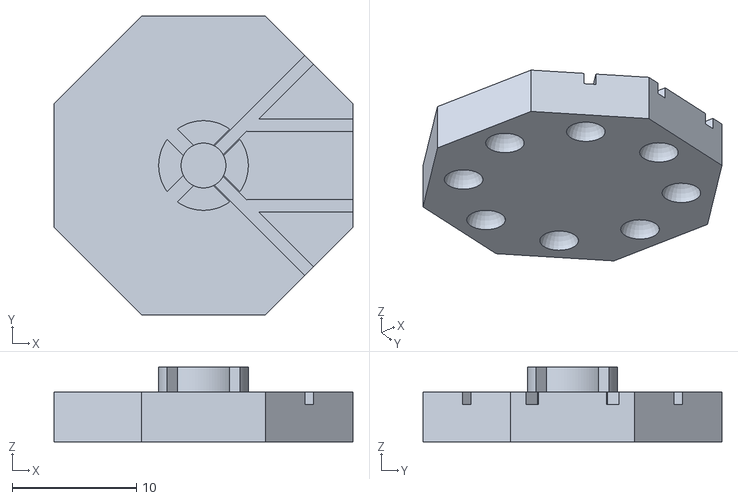
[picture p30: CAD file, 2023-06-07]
Expansions/X-Wing_Compatibility/STLs/plane_xwing_tmg.stl
24.0 x 24.0 x 6.00

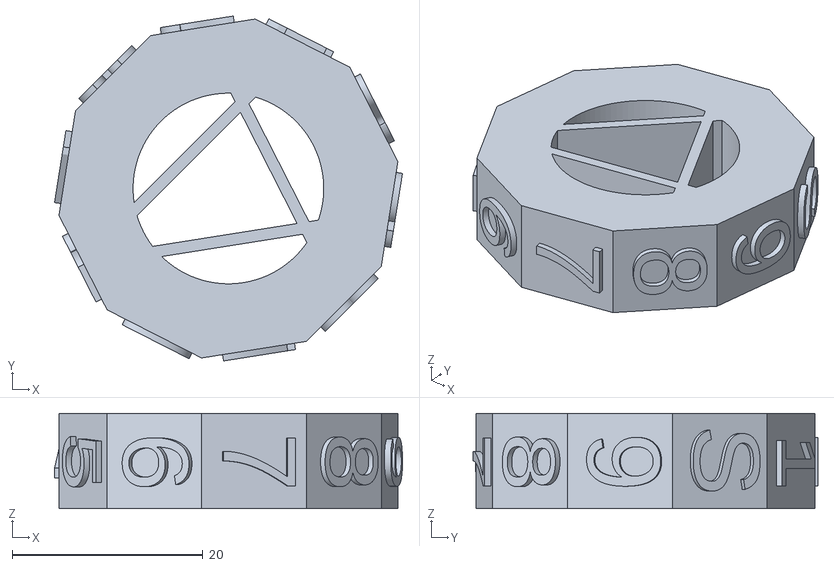
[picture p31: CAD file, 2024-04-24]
STLs/statwheel_S.stl
36.5 x 36.2 x 10.0

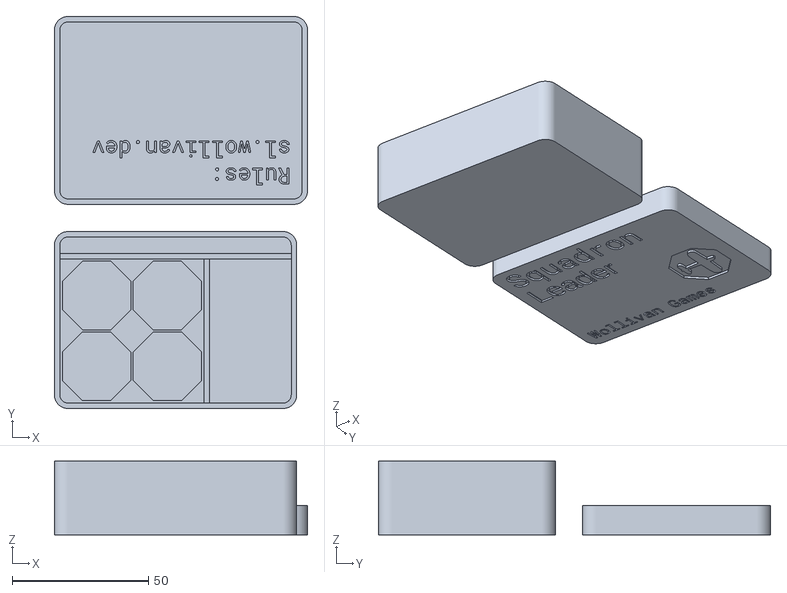
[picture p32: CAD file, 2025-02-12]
3DPrinting/STLs/box.stl
93.0 x 144.0 x 27.0

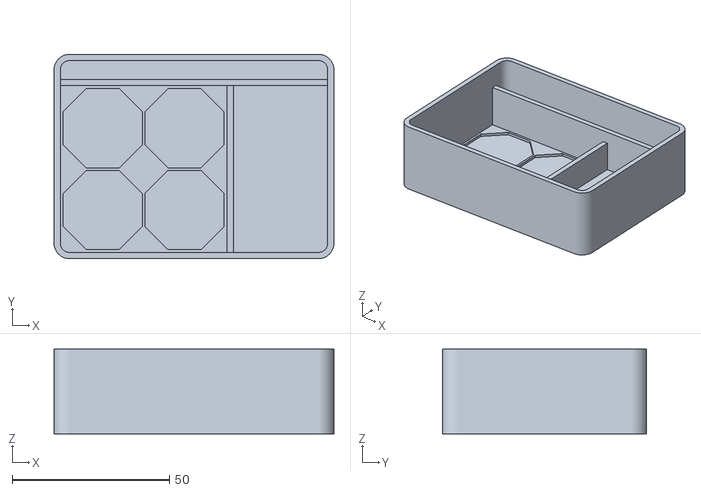
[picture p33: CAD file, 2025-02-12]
3DPrinting/STLs/individual_models/boxv2_base.stl
89.0 x 65.0 x 27.0

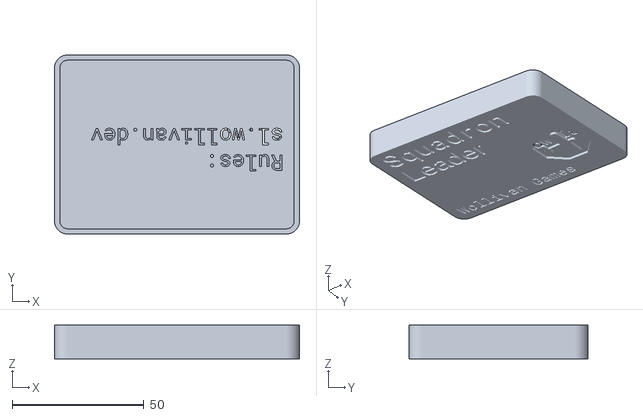
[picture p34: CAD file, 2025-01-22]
3DPrinting/STLs/individual_models/v1/box_top_small.stl
93.0 x 68.0 x 12.8

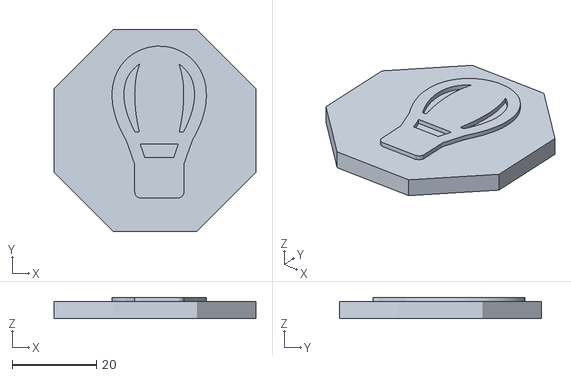
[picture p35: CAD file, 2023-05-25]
Expansions/Bombers_and_Balloons/STLs/balloon.stl
48.0 x 48.0 x 5.00

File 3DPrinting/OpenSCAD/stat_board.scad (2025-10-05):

include <variables.scad>;
// board should fit in the dice section of the small box
boardWidth = 24; // dice are 12mm
boardLength = 45; // dice are 12mm
boardHeight = 2;
gap = boardLength/5;

config2334 = ["2", "3", "3", "4"];
config2343 = ["2", "3", "4", "3"];
config2433 = ["2", "4", "3", "3"];
config3234 = ["3", "2", "3", "4"];
config3243 = ["3", "2", "4", "3"];
config3324 = ["3", "3", "2", "4"];
config3342 = ["3", "3", "4", "2"];
config3423 = ["3", "4", "2", "3"];
config3432 = ["3", "4", "3", "2"];
config4233 = ["4", "2", "3", "3"];
config4323 = ["4", "3", "2", "3"];
config4332 = ["4", "3", "3", "2"];
config4422 = ["4", "4", "2", "2"]; // bomber

module roundedCube(width, length, radius, height) {
  hull () {
    translate ([radius,radius,0])
      cylinder (r=radius,h=height);
    translate ([radius,width-radius,0])
      cylinder (r=radius,h=height);
    translate ([length-radius,width-radius,0])
      cylinder (r=radius,h=height);
    translate ([length-radius,radius,0])
      cylinder (r=radius,h=height);
  }
}


module number(val, x) {
  translate([x, 9, -1])
    linear_extrude(boardHeight+2)
      text(val, font="RobotoMono", valign="top", size=6);
}

module symbol(s, path, x) {
  translate([x,boardWidth-10,-1])
      linear_extrude(height = boardHeight+2) {
          scale(s)
              import(path);
      }
}

module board(stats) {
  difference() {
    roundedCube(boardWidth, boardLength, 3, boardHeight);

    symbol(0.5, "icons/health.svg", 2.25);
    translate([0,-0.25,0]) symbol(0.45, "icons/defense.svg", 13.75);
    translate([0,-0.75,0]) symbol(0.55, "icons/attack.svg", 23.75);
    symbol(0.5, "icons/speed.svg", 35.75);


    number(stats[0], 3.75);
    number(stats[1], 14.75);
    number(stats[2], 25.75);
    number(stats[3], 36.75);

    // translate([1.5, 9, -1])
    //   linear_extrude(boardHeight+2)
    //     text(order, font="RobotoMono", valign="top", size=6);
  }
}

// board(config2334);
// board(config2343);
// board(config2433);
// board(config3234);
// board(config3243);
// board(config3324);
// board(config3342);
// board(config3423);
// board(config3432);
// board(config4233);
// board(config4323);
// board(config4332);
board(config4422); // bomber

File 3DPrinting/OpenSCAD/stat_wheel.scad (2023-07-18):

$fn=100;
wheelWidth = 8;
wheelDia = 16;
sideWidth = wheelWidth/2;

sideSize = wheelDia;

axelDia= wheelDia/3;
axelLength = wheelWidth*5;

sideNum = 5;
axelSides = 10;

springLength = wheelDia*0.8; // determined empirically
springWidth = 1.2; // determined arbitrarily, adjust for feel
springOffset = axelDia/2*sin(2*360/10); // determined with magic

// test();
// wheelSet();
// rotate([0,0,360/10]) axel();
side();


module axel(mod){
  union() {
      rotate([0,0,18])
        cylinder(h=axelLength+1, d=axelDia, $fn=axelSides);
      translate([-axelDia/2, -axelDia/2,0])
        cube([axelDia/2, axelDia/2, sideWidth]);

      translate([-axelDia/2, -axelDia/2,1+axelLength-sideWidth])
        cube([axelDia/2, axelDia/2, sideWidth]);
  }
}

module springs(){
  translate([-springLength/2,springOffset,0])
    cube([springLength,springWidth,wheelWidth]);

  rotate([0,0,36*4])
    translate([-springLength/2,springOffset,0])
      cube([springLength,springWidth,wheelWidth]);

  rotate([0,0,36*7])
    translate([-springLength/2,springOffset,0])
      cube([springLength,springWidth,wheelWidth]);
}

module numbers(icon, yMod, zMod) {
  // numbers
  rotate([0,0,35])
    for (n=[1:sideNum-1])
      rotate ([0,0,(n)*360/sideNum])
        translate([wheelDia/2.75,-wheelWidth/2.5,wheelWidth*0.82])
          rotate([0,90,0])
            linear_extrude(2.5)
              text(str(n), size=7);

   // symbol
  rotate ([0,0,36])
    translate([wheelDia/2.75,-wheelWidth*yMod,wheelWidth*zMod])
      rotate([0,90,0])
        linear_extrude(2.5)
          scale(0.4) import(icon);                
}

module wheel(icon, yMod, zMod) {
  rotate([0,0,-53]) // used just to determine where the arrow should go
    union() {
      difference(){
        cylinder($fn=100, h=wheelWidth, d=wheelDia);

        translate([0,0,-1])
          cylinder(h=wheelWidth+2, d=axelDia*2);
      }

      springs();

      numbers(icon, yMod, zMod);
    }
}

module side () {
  tran = sideSize/3.5;
  difference () {
    hull () {
      translate ([tran,tran,0])
        cylinder (r=5,h=sideWidth);
      translate ([-tran,tran,0])
        cylinder (r=5,h=sideWidth);
      translate ([0,-tran,0])
        cylinder (r=5,h=sideWidth);
      // translate ([-tran,-tran,0])
      //   cylinder (r=5,h=sideWidth);
    }
    // top marker
    translate([0,-sideSize/1.8,wheelWidth/4])
      cube([3,2,wheelWidth], true);
    // translate([0,-sideSize/2,wheelWidth/2-1])
    //   rotate([90,0,0]) rotate([0,0,90])
    //     cylinder($fn=3, h=2, r=3);

    // axel hole (obviously)
    translate([0,0,0])
      axel();
  }
}

module health() {
  wheel("icons/health.svg",0.375, 0.86);
}

module defense() {
  wheel("icons/defense.svg",0.4, 0.87);
}
module attack() {
  wheel("icons/attack.svg",0.4, 0.865);
}
module speed() {
  wheel("icons/speed.svg",0.35, 0.85);
}
module wheelSet() {
  translate([0,0,0]) health();
  translate([wheelDia+5,0,0]) defense();
  translate([wheelDia+5,wheelDia+5,0]) attack();
  translate([0,wheelDia+5,0]) speed();
}




module test() {
  axel();
  side();
  translate([0,0,sideWidth]) health();
  translate([0,0,sideWidth+wheelWidth]) defense();
  translate([0,0,sideWidth+wheelWidth*2]) attack();
  translate([0,0,sideWidth+wheelWidth*3]) speed();
  translate([0,0,1+sideWidth+wheelWidth*4]) side();

}

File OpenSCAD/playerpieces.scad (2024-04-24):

tokenHeight = 4;
tokenWidth = 26;
wallWidth = 6;
$fn = 100;

arcWidth = 1;

templateGapOffset = tokenWidth/6;
templateLength = tokenWidth*3;

module token(){
    translate([0,0,0])
    //cube([tokenWidth,tokenWidth,tokenHeight], true); 
    rotate([0,0,135/2])
        cylinder(h=tokenHeight, d=tokenWidth, $fn=8); 
}


module tokenWithArc(){
    difference(){
        token();
        
        //weird z +1 and +2 height because its centered and this ensures no very thin line consufing the printer
        translate([tokenWidth/3,tokenWidth/3,tokenHeight-arcWidth/2+1]) 
            rotate([0,0,135/3])
                cube([tokenWidth,arcWidth,arcWidth+2], center=true);
        
        
        translate([tokenWidth/3,-tokenWidth/3,tokenHeight-arcWidth/2+1]) 
            rotate([0,0,-135/3])
                cube([tokenWidth,arcWidth,arcWidth+2], center=true);
            
        
        translate([tokenWidth/3,tokenWidth/8,tokenHeight-arcWidth/2+1]) 
            cube([tokenWidth/2,arcWidth,arcWidth+2], center=true);
        
        
        translate([tokenWidth/3,-tokenWidth/8,tokenHeight-arcWidth/2+1]) 
            cube([tokenWidth/2,arcWidth,arcWidth+2], center=true);
    }
}

module balls(zMod, dMod) {
    //they used to be procedurally generated but now there are only four, this was easier
//    for (n=[0:4])
//            rotate ([0,0,(n-1)*360/5])
//                translate([tokenWidth/2-wallWidth,tokenWidth/4,zMod])
//                    sphere(d=wallWidth/2+dMod, $fn=25);
    
    translate([tokenWidth/4,tokenWidth/4,zMod])
        sphere(d=wallWidth/2+dMod, $fn=25);
    translate([-tokenWidth/4,tokenWidth/4,zMod])
        sphere(d=wallWidth/2+dMod, $fn=25);
    translate([-tokenWidth/4,-tokenWidth/4,zMod])
        sphere(d=wallWidth/2+dMod, $fn=25);
    translate([tokenWidth/4,-tokenWidth/4,zMod])
        sphere(d=wallWidth/2+dMod, $fn=25);
}





module plane(){
    color("green") tokenWithArc();
    
    translate([0.5,1,tokenHeight])
        linear_extrude(height = tokenHeight/4) {
            scale(0.065)
                import("plane-model.svg", center=true);
    }
}


module templateStraight() {
    difference(){
        cube([tokenWidth,templateLength,tokenHeight]);
        
        translate([tokenWidth/2,-templateGapOffset,-1])
            rotate([0,0,135/2])
                cylinder(h=tokenHeight+2, d=tokenWidth, $fn=8);
        
        
        translate([tokenWidth/2,templateLength+templateGapOffset,-1])
            rotate([0,0,135/2])
                cylinder(h=tokenHeight+2, d=tokenWidth, $fn=8);
        
        translate([tokenWidth/7,templateLength/3,tokenHeight/2])
            linear_extrude(tokenHeight)
                text("1", size=25);
    }
}
/*
guess = 0.02; //i need someone cleverer than me to work out the calculations for the 45 degree template
module template45old() {
    difference(){
        translate([-templateLength,0,0])
            rotate_extrude(angle = 45)
                translate([templateLength, 0, 0])
                square(size = [tokenWidth, tokenHeight]);
        
        
        translate([tokenWidth/2,-templateGapOffset,-1])
            rotate([0,0,135/2])
                cylinder(h=tokenHeight+2, d=tokenWidth, $fn=8);
        
        
//        translate([-templateGapOffset/1.25+tokenWidth,templateGapOffset/1.25+tokenWidth*2.45,-1])
//        translate([-templateLength/4+templateGapOffset/2,templateLength-tokenWidth/2+templateGapOffset/2,-1])
        translate([-templateGapOffset+guess*tokenWidth-tokenWidth/2,templateLength-tokenWidth/2.5+guess,-1])
            rotate([0,0,135/2])
                cylinder(h=tokenHeight+2, d=tokenWidth, $fn=8);
    }
}
*/

module template45() {
    difference(){
        translate([-templateLength,0,0])
            rotate_extrude(angle = 45)
                translate([templateLength, 0, 0])
                square(size = [tokenWidth, tokenHeight]);
        
        
        translate([tokenWidth/2,-templateGapOffset,-1])
            rotate([0,0,135/2])
                cylinder(h=tokenHeight+2, d=tokenWidth, $fn=8);
        
        
        translate([-templateLength * sin(45/360)-(tokenWidth/1.6),-templateGapOffset+templateLength * cos(45/360)-tokenWidth/4,-1])
            rotate([0,0,135/2])
                    cylinder(h=tokenHeight+2, d=tokenWidth, $fn=8);
        
        
        translate([tokenWidth/8,templateLength/4,tokenHeight/2])
            rotate([0,0,30])
                linear_extrude(tokenHeight)
                    text("2", size=25);
        
        
    }
    
}

module template90() {
    difference(){
        translate([0,0,0])
            rotate_extrude(angle = 90)
                translate([templateLength/3, 0, 0])
                square(size = [tokenWidth, tokenHeight]);
        
        
        translate([tokenWidth*1.5,-templateGapOffset,-1])
            rotate([0,0,135/2])
                cylinder(h=tokenHeight+2, d=tokenWidth, $fn=8);
        
        
        translate([-templateGapOffset,templateLength/2,-1])
            rotate([0,0,135/2])
                cylinder(h=tokenHeight+2, d=tokenWidth, $fn=8);
        
        
        translate([tokenWidth/0.9,templateLength/6,tokenHeight/2])
            rotate([0,0,45])
                linear_extrude(tokenHeight)
                    text("3", size=25);
    }
}
//altitude token
module altitudeTranslated(){
    translate([0,-60,0])
    union(){
        balls(zMod=tokenHeight, dMod=0);
        difference(){
            token();


            translate([0,0,-1])
                scale([0.56,0.56,1.5]) 
                    token();
            
            balls(zMod=0, dMod=0.25);
        }
    }
}
//plane token
module planeTranslated(){
    translate([0,-30,0])
    difference(){
        plane();

        balls(zMod=0, dMod=0.25);
    }
}


//test
//color("green") rotate([0,0,315]) translate([tokenWidth*3,0,0]) template45();


//blank token
//difference(){
//    tokenWithArc(); 
//        balls(zMod=0, dMod=0.25);
//    }





/*Actual models*/
translate([-tokenWidth*2,0,0]) templateStraight();
translate([tokenWidth*3,0,0]) template45();
template90();
altitudeTranslated();
planeTranslated();

/*Actual models*/

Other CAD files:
3DPrinting/STLs/stat_board.stl
Expansions/Bombers_and_Balloons/bomber_stat_board.stl
3DPrinting/OpenSCAD/expansions/mustang.stl
3DPrinting/STLs/individual_models/stat_board_number_variations/2343.stl
Expansions/Star_Wars/falcon.stl
3DPrinting/OpenSCAD/bombers_and_balloons.scad
3DPrinting/OpenSCAD/box.scad
3DPrinting/OpenSCAD/expansions/bombers_and_balloons.scad
3DPrinting/OpenSCAD/expansions/mustang.scad
3DPrinting/OpenSCAD/expansions/star-wars.scad
3DPrinting/OpenSCAD/expansions/star-wars.stl
3DPrinting/OpenSCAD/expansions/xwing_compatible.scad
3DPrinting/OpenSCAD/manoeuvre_template.scad
3DPrinting/OpenSCAD/modules.scad
3DPrinting/OpenSCAD/player.scad
3DPrinting/OpenSCAD/preview.scad
3DPrinting/OpenSCAD/previous_versions/v1/box.scad
3DPrinting/OpenSCAD/previous_versions/v1/stat_board.scad
3DPrinting/OpenSCAD/previous_versions/v1/stat_board_w_health.scad
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

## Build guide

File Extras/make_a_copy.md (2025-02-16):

# Getting a Copy of the Game

If you have a working 3D printer, you have all you need to make a copy of the game! [Get the files here](https://github.com/Wollivan/SquadronLeader/tree/main/3DPrinting/STLs).
If you DON'T have a printer, I do, so you can [get a copy here](https://squadronleader.wollivan.dev/buy-a-copy).

## Printing instructions

There are only 3 assets that **need** to be printed.

- player.stl (one for each printer)
- manoeuvre_template.stl
- range_ruler.stl

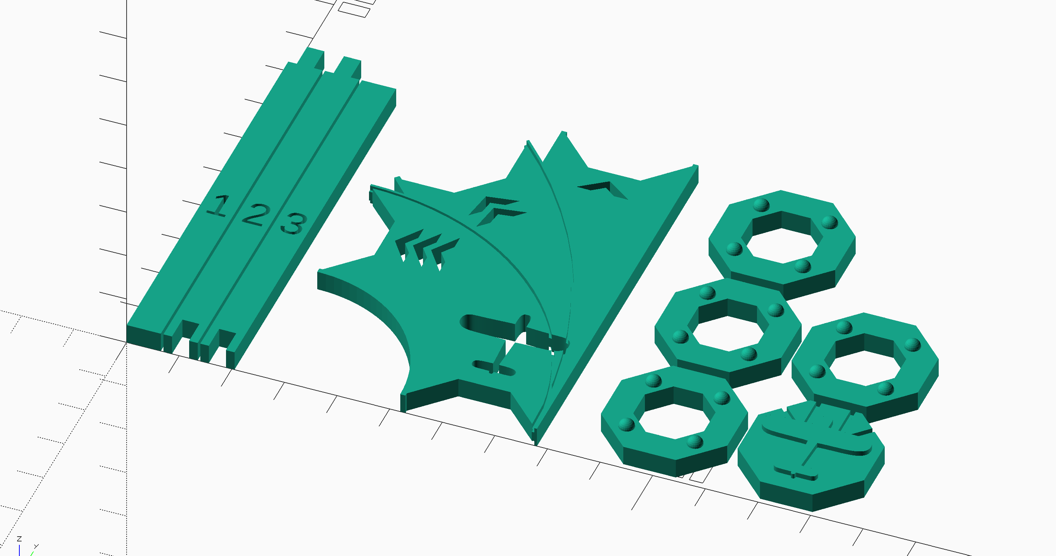
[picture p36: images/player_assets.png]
player_assets


Or you can print a box set which includes the following:

- player.stl x4
- manoeuvre_template.stl
- range_ruler.stl
- box.stl
- stat_board.stl

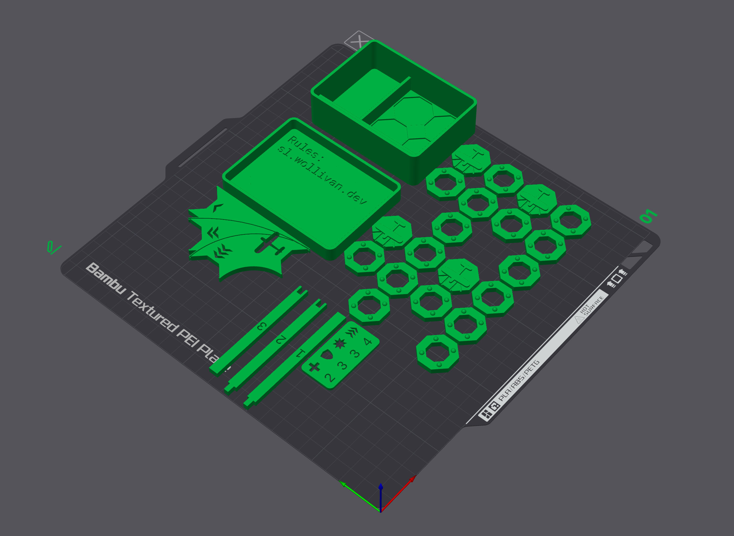
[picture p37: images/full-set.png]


### To Buy:

- 4 green dice
- 4 red dice

For the dice, 12mm dice fit nicely in the printable box.

_Also to note, the colours in the copy you can buy are Overture Matte PLA._

### Optional Stat Trackers

The most basic option for printing something to show the stats is to print the stat_board in the STLs folder. There are different configurations in the individual_modles/stat_board_number_variations folder. But, if you want something fancier, 2 options are below:

- Within the v1 folder in STLs (on GitHub) there are stat wheels, axels and sides, print each of these to create stat wheels that fit in the v1 box.
- If you don't want to print stat wheels then use this <a href="https://planes.wollivan.dev/" target="_blank">online stat tracker</a> (or just remember your stats/write them on a piece of paper/cheat).

### Optional fancy box topper:

FancyBoxTopper.stl is glued onto FancyBoxTop.stl. The topper is 'divided' into 5 levels to be able to perform filament swaps of different colours. The bottom level of the topper is .6mm giving 3, .2mm layer passes. All other levels are .4mm allowing 2, .2mm layer passes.

- If you are having a large dogfight and don't have enough different colour filaments, you can print the stat boards from the "extras" folder which have identifying letters".

### Rules Quick Reference Cards

There are 2 images that, when printed back to back, create a trifold quick reference rules book. You can find them <a href="https://github.com/Wollivan/SquadronLeader/tree/main/3DPrinting/STLs" target="_blank">here</a>.

## Downloads

You can download all the printable assets from GitHub. We aren't on any STL sharing sites because they don't allow continuous development with a GitHub repo, so this is the only place you can find us!

<a href="https://github.com/Wollivan/SquadronLeader/tree/main/3DPrinting/STLs" target="_blank" class="button">Download STLs</a>

<a href="https://github.com/Wollivan/SquadronLeader/tree/main/3DPrinting/OpenSCAD" target="_blank" class="button">Download OpenSCAD files</a>

The game was originally designed to fit in old tobacco tins, so it is joyful to see copies of this in old tins!
If you want a classic Squadron Leader tobacco tin without getting out a small loan <a href="https://www.etsy.com/uk/listing/273646926/all-reserved-vintage-squadron-leader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" target="_blank">you can get an imitation here</a>.

#### Example print

This amazing set was printed by Greg (who also designed the first score keeper pieces)

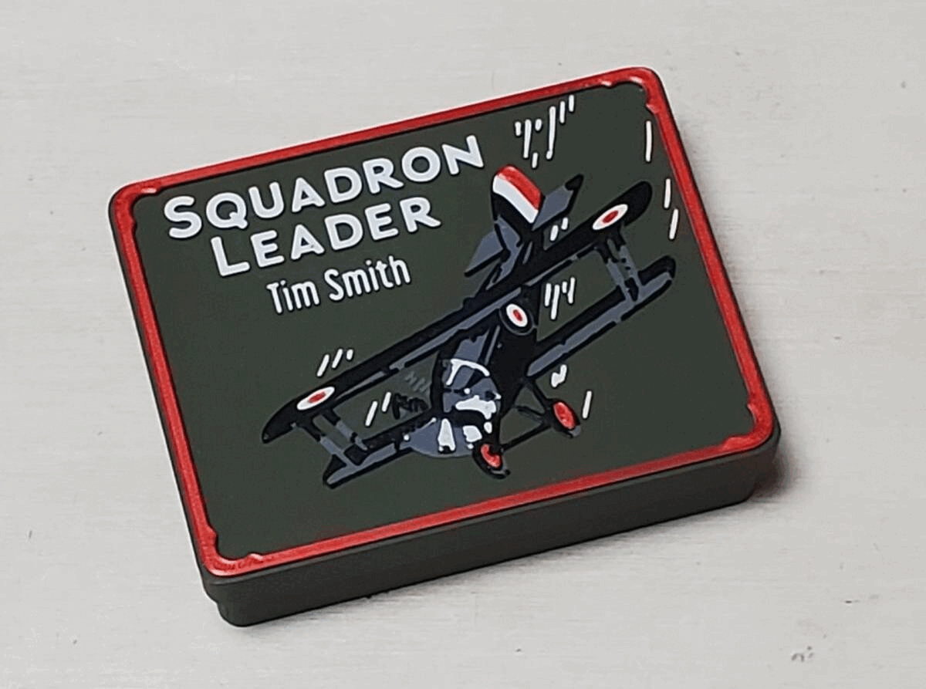
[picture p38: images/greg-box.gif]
greg-box


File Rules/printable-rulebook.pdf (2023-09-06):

## Advanced Manoeuvres

Barrel Roll

Cost Manoeuvre cost doubled

Action Don't rotate plane after manoeuvre

Dive Bomb

Cost After an attack, reduce altitude to match defender that is within range 1 and roll d6

Action On a result of 2-6 deal one damage. On a result of 1 take one damage

Immelmann

Cost Eliminate opponent

Action +3 altitude, straight and 180° turn

Push the Envelope

Cost During Manoeuvre stage, roll d6

Action On a result of 5-6 gain 1 this round OR 1 extra altitude. On a result of 1-4 take one damage

Split S

Cost 4 altitude

Action Turn 180° after manoeuvre

# Squadron Leader

Full rules and stat tracker at:

squadronleader. wollivan.dev

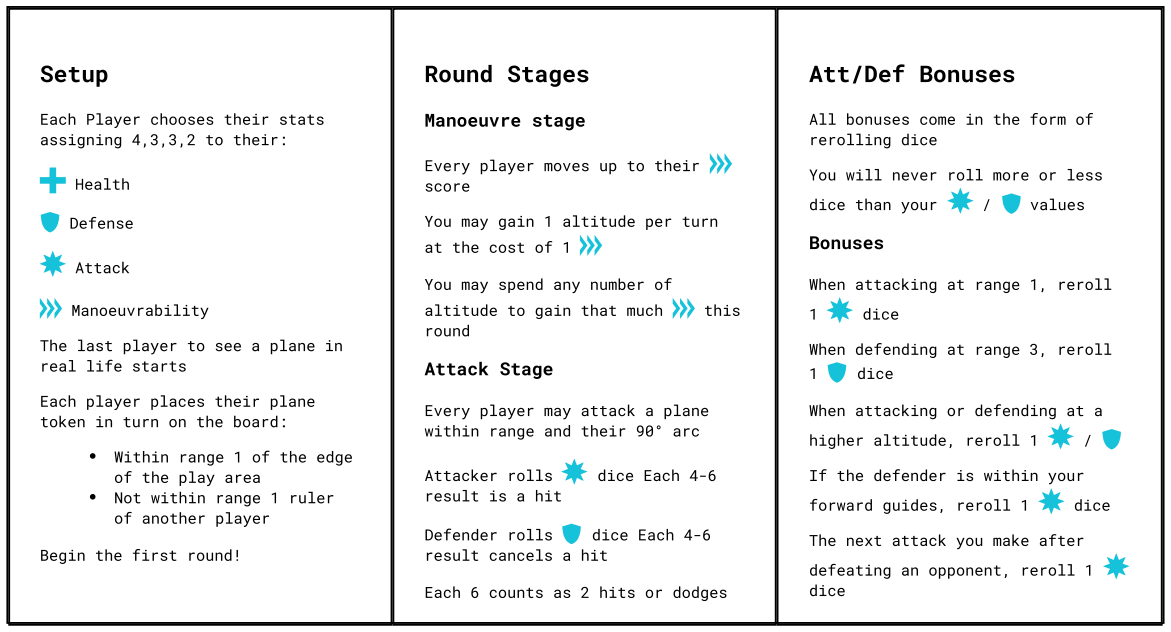
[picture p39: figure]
Setup; Each Player chooses their stats assigning 4,3,3,2 to their:; Health; Defense; Attack; Manoeuvrability; The last player to see a plane in real life starts; Each player places their plane token in turn on the board:; Within range 1 of the edge of the play area Not within range 1 ruler of another player; Begin the first round!; Round Stages; Manoeuvre stage; Every player moves up to their score; You may gain 1 altitude per turn; at the cost of 1; You may spend any number of; altitude to gain that much; this; round; Attack Stage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

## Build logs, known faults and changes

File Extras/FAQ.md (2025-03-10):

# FAQ

### Can you print me a copy?

Currently no, but its something we are working towards!

### What happens when I try to execute a manoeuvre but my opponents plane token is in the way?

If you can't execute a manoeuvre without finishing it in the same place as an opponent, you can't choose that manoeuvre.

However, if you need to move an opponent's token out of the way so you can put the manoeuvre template down you can move the other players token, but use an altitude token next to where the moved token was to make sure you don't forget where it was originally.

### My opponent just rolled three 6s on the attack dice, what can I do?

Hope you have enough Health left and roll very well, that pilot has good aim!

### The rules for Split S say I can't execute it on the same turn as I gain altitude. Does this mean I can't do an Immelmann after a knockout?

No. The altitude gained from an Immelmann does not count, so you could do a Split S, then proceed to Immelmann during the attack stage after taking an opponent out!

Anyone who manages that... Well that's one hell of a pilot!

### Does a critical hit do more damage?

The benefit of a critical hit is it's difficult to dodge. Think of it as a very accurate shot. It still only counts as one!

that-still-only-counts-as-one-lotr

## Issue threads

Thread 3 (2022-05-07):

Turn Sequence

lifelike, 2022-05-07:
From what I can see there is no part of the rules that explains what the order of things are? There is a Move Stage and an Attack Stage. Are they carried out in that order, by each player, or do all players move first and then all players attack? Or some other order? I think it needs to be clarified.

Wollivan, 2022-05-08:
Great point, I will add some clarification today. to the rules!

Its everyone move in order, everyone attack in order btw :)

Wollivan, 2022-05-08:
Fixed in PR 20 thanks!

Closed 2022-05-08.

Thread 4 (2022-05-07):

Maximum Altitude

lifelike, 2022-05-07:
The rules make no mention of what the maximum altitude is. Each player is given 4 altitude tokens, so 4 is possibly the maximum? But the description of the Immelmann seems to imply 3 ("may gain 3 altitude tokens (or up to 3 if they already have 1, 2 or 3)"), or is it just that for some reason you will only be able to get to altitude 3 even if there is also a 4th altitude? Sounds like an unnecessary complication if that is the case?

Wollivan, 2022-05-08:
Wow I can't believe I hadn't clarified this! I will update the altitude rules today, thank you!

Wollivan, 2022-05-08:
Fixed in PR 21.

Closed 2022-05-08.

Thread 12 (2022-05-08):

Rules for larger battles

Wollivan, 2022-05-08:
If there were teams of 10+ ships being piloted by one or two people, the game would benefit from an additional set of rules for smoother gameplay, but until it can be tested, I'm not sure what those rules are.

Level0gamedev, 2023-11-26:
I think it's more-or-less agreed in the wargaming hobby that the UGIO (You Go, I Go - you activate all your pieces, move them, resolve combat, etc. then I do the same with all of mine) is not a great solution for larger battles. Not to mention, it it doesn't really fit with the idea of a chaotic and fast paced dogfight. We can look at other wargames to find a better solution for activation.

The easiest approach is "alternating activation" - you activate one guy, then I activate one of mine and so on. The problem with alternating activation when having 10+ units under your command is that it would be easy to forget which model "went" this turn, and which didn't. Fortunately it can be solved using existing components.

Fortunately we have stat cards/wheels for each plane, so a quick solution would be to just rotate the stat card/wheel of a plane you activate 90 degrees. This way you can quickly see which planes can still move on this turn, and when all stat cards/wheels are rotated, the players rotate them back.

Alternating activation would make the game more dynamic, but I would argue that it doesn't do that good of a job at simulating WW1 dogfight (reading some accounts of the pilots of the era, you really get a feel for how chaotic it was). If I were to run/play in a game where each player has 10+ units I would push it further into chit-pull system activation.

Each plane gets its own token (could be as simple as printing a disk or a cube of the color of the plane, but other identification as described in #68) thrown into a bag. Player pulls a token at random and that plane activates. Then another chit is pulled at random and that plane activates, and so on. I would even add a "blank" chit (of the color the non player-components are, like the maneuver template or box are) that signifies that turn end and putting all the chits back into the bag. This would make the large game more representative of a large ww1 air battle, while still keeping it fun to play.

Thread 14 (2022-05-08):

Score keeping aperatus

Wollivan, 2022-05-08:
Rather than relying on the possession of a pen and pad, create something that can help players see which plane has what stats.

This could also be integrated into a storage solution.

Teque5, 2022-05-08:
Yea there should be an elegant 3d-printed solution for this.

Wollivan, 2022-05-08:
There's been a few ideas floated on the Reddit posts, so I am going to have a think, but there is no reason why all the options are available to print (dials, counters etc)

amnos0405, 2022-05-16:
Someone posted a design up on reddit for a stat tracker. I got inspired by it and created a test. Let me know what y'all think or any possible improvements. My one thought is that if a printer is not dialed in correctly the numbers will not be too clear. Printing them number side down helps though. I'd be happy to make a branch for a pull once ideas have been thrown around.

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

Wollivan, 2022-05-16:
Wow this is amazing! Really neat idea, and great thinking about printability on all printers.

You could also use dots instead of numbers if that would be clearer?

lifelike, 2022-05-16:
That looks so good I think it will make the entire game look much more fun when set up!

One thought is that, since it is printed in 3D and all, it is probably possible to make the display so that it hides all the digits (or, well dots) except for the relevant one? If the tokens with digits are thinner than the display they could be slotted in below it so that only one digit is visible in a window. Or one digit could protrude below the display with the rest hidden. Makes the display slightly bigger, but I think it looks a bit busy with all the digits visible.

Wollivan, 2022-05-16:
Also just to add, I love these symbols and can't wait to print my set of these!

If you don't make it with dots, please keep the version with numbers too :)

amnos0405, 2022-05-16:
> If the tokens with digits are thinner than the display they could be slotted in below it so that only one digit is visible in a window. Or one digit could protrude below the display with the rest hidden. Makes the display slightly bigger, but I think it looks a bit busy with all the digits visible.

Great idea and good eye lifelike, it is very busy with all numbers showing. I've got an idea in my head on how to implement the hidden slot without making the display too much bigger.

> Also just to add, I love these symbols and can't wait to print my set of these!

> If you don't make it with dots, please keep the version with numbers too :)

Wollivan, i'll make a branch tonight with the stls so folks can get a feel for them if wanted... And dots...

lifelike, 2022-05-16:
Had another thought that maybe it is possible to make slots along one side to track remaining life with some kind of arrow/triangle thing moved down. Similar to the slots along the "bottom" side, but smaller. Possibly more ergonomic to move a small marker down to the next slot when hit compared to rotating one of those bigger markers.

Wollivan, 2022-05-17:
Hey one more thought I had, the numbers don't need to all be present on the counters, you could just have one big number in the middle, and make one 2, two 3s and a 4.

amnos0405, 2022-05-17:
A bit of a combination of everyone's ideas... I tried the concealing idea and it got too crammed/complex. Thoughts on accessibility/language of dots vs numbers? Or let's keep both!

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

Making a pull request now, would like to hear feedback before it's merged in.

lifelike, 2022-05-17:
My 2c: I am not a fan of using dots like that, because of how it looks like dice. To me it implies some value to roll ("roll 3+ to hit"), not "this is how many dice you need to roll" or "this is how much health this plane has".

Wollivan, 2022-05-17:
> Thoughts on accessibility/language of dots vs numbers? Or let's keep both!

I think keep both, just give people a choice.

In regards to language, I'm happy to be corrected here, but I believe those numbers have become ubiquitous, but again happy to be wrong!

Wollivan, 2022-05-17:
Also I like the life counter notches :)

amnos0405, 2022-05-17:
First test print of all the pieces. Happy with most of it, going to make a few small tweaks (dots too high, width of board needs to reduce by ~1mm so it fits standing in the box). Doing a play test today at lunch for a real world experience, table flipping and all.

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

Wollivan, 2022-05-17:
Off topic, but is that the bendable range ruler?!

Wollivan, 2022-05-17:
This is so cool, I flipping love al the colours, really grateful for all you've added to the game (so far)!

Wollivan, 2022-05-17:
> It is! Printed with TPU...but by TPU's nature the numbers on it are stringy and not very crisp. Also if that thing has room to expand quickly in the box, pieces can go flying (it has caused a scavenger hunt for dice a couple of times already). I would say a hard ruler that can snap together with dovetailing, etc, would be better.

Well I had better add it back to the files then because I removed it!

> I saw the post on Reddit and fell in love with the game (I'm a sucker for small box games too). It's been super fun to collaborate on with everyone. It's shown me I should learn OpenSCAD though, as Blender is not best for customizations/collaboration.

Yeah it's been so fun and weird working with people I've never met on something I've spent months dreaming up. It's been so rewarding, I was blown away by the initial response on Reddit. Thinking of making a new Reddit post soon with an update, but want it to be meaningful!

Did you get a chance to play with your designs today?

amnos0405, 2022-05-18:
I did play with my coworker today at lunch, twice actually (I won both thank you). He really enjoyed it too, and he's familiar with X Wing. Said this was a great lightweight reimagining. He understood the rules well too.

As for the pieces, they needed some adjustment. They have no weight to hold themselves down so any table shake or fumbling fingers can cause havoc. He had a great idea for the health tracker and I noodled with the stat chits...printing a quick proof of the changes now.

amnos0405, 2022-05-19:
Ok, final iteration I think. Very happy with it's stability and trimness. I'll post the full on glamour shots on Reddit.

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

Wollivan, 2022-05-19:
Oh boy, these are so good looking! Excellent work!

If you're up for it. Big if. Pictures of your set always look amazing, and the website would benefit from a shot of all your components together top down. If you are willing to take one of course!

Wollivan, 2022-05-19:
How did you do the grey inside the numbers?

amnos0405, 2022-05-19:
I'll definitely take some top down shots for you.

The grey inside is achieved by setting a filament swap in the slicer...then another back to the original color after the grey layer.

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

Also there's another branch to merge =)

amnos0405, 2022-05-20:
@Wollivan got some top down shots, let me know if these work well. Also really like the dovetail ruler, already substituted out the bendy one.

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

Wollivan, 2022-05-20:
> @Wollivan got some top down shots, let me know if these work well. Also really like the dovetail ruler, already substituted out the bendy one.

Greg these are incredible, this looks so freaking good!

Wollivan, 2022-05-31:
I'm going to close this issue because I love what you've made Greg!

If anyone else has made alternatives don't think me closing this issue means you can't share it!

Closed 2022-05-31.

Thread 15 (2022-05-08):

Printable storage

Wollivan, 2022-05-08:
It would be ideal for people who are printing a copy to be able to have a purpose built box to store their game.

amnos0405, 2022-05-09:
Working on a custom topper that is traced from the Squadron Leader tin (i posted on the Reddit thread). Figured the [tin here](https://www.thingiverse.com/thing:713187) could be used and my topper just glued on.

Wollivan, 2022-05-09:
Someone beat you to the punch, and I thought it was you!

Please don't stop though, looking forward to the plane box!

amnos0405, 2022-05-09:
No worries @Winehorn. Like your clean and simple to print design. I'll still finish mine because variety is the spice of life, plus I'm having fun with it.

Wollivan, 2022-05-17:
Hey @amnos0405 @Winehorn are you both happy with your representation in the box files on the repo?

If you are I will close the issue, but no pressure if you're still working on yours!

Wollivan, 2022-05-17:
@Winehorn could I ask a huge favour of you, to upload the box and lid as separate STLs?

amnos0405, 2022-05-18:
@Wollivan I'm good with you closing the issue.

Closed 2022-05-19.

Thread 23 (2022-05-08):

Hexagons are the Bestagons

Teque5, 2022-05-08:
I started remixing this design for a hexagon-based layout (since clearly we all love hexagons), but I'm wondering if the reduction in the firing arc from 90° to 60° will have a large adverse effect on gameplay. I'm printing your original design now (with some tweaks) so I have yet to actually play this.
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

Wollivan, 2022-05-08:
I don't think it would have a negative effect on gameplay no, it would just make it more challenging, and maybe that's a good thing?

Wollivan, 2022-05-08:
Great idea by the way!

Wollivan, 2022-05-08:
lifelike just made a pull request that's similar to what you're working on.

I've merged it, so it's on main now, have a look and see what came up with that was different/the same.

I will add a model tomorrow that has a 60 firing arc, and still leave the 90 on there, but you have got me thinking about whether it should be 60 instead.

Wollivan, 2022-05-08:
Sorry for spamming, I'd love to see all the tweaks to the models, perhaps they should be the default!

lifelike, 2022-05-09:
I don't really think what I did with the hex grid is similar to this. If anything it is actually quite annoying to have hex-shaped playing pieces moving on a hex grid, so the rectangular ones were just fine. Plus the arc of fire that I came up with is closer to 90-degrees in the hex grid rules.

That model looks nice though. I guess the movement templates has to be modified as well to fit this shape?

Wollivan, 2022-05-09:
You know I didn't even notice the model in the first comment was Hexagon! I did like the look of it though, a cleaner look maybe?

I think for the hex grid rules the model doesn't HAVE to change, but I don't want anyone to have wasted time making anything, so always make a PR, even if it just goes to another modular rule set or something.

The more the merrier!

Teque5, 2022-05-11:
I finished printing the original design but soon realized it didn't fit in an altoids tin, only that larger out-of-print Squadron Leader Tin size. With that in mind I went back just now and did some simulated packing to see if I could **actually** fit everything in a single modern tin.

If we scale the hexagons to 22x25.4x2ish mm then it would be possible to put (6) players worth of airplanes, (12) 12mm d6 small dice, and all (3) movement pieces into the interior space of a normal tin. I think (?) a string would also fit.
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

If people are interested I can move forward. I would need to design the movement cards and a tin insert. For the movement cards I'm not exactly sure how long the (1,2,3) move pieces should be relative to everything else? It looks like the length of the move 1 piece is like 3.5x the square size of the octagonal original but I dunno.

Wollivan, 2022-05-11:
Wow this is incredible!!

If you want to let me know exactly how wide/tall you want the planes and altitude tokens (excluding the plane image and nubs) I can just export some STLs specifically that scale.

It's all done in OpenSCAD, so I can just scale it there rather than anyone having to redesign anything. It took me so long to get the maneuver templates to be mathematically satisfying.
They are all technically the same "length" just bent.

Wollivan, 2022-05-11:
Wow this is incredible!!

If you want to let me know exactly how wide/tall you want the planes and altitude tokens (excluding the plane image and nubs) I can just export some STLs specifically that scale.

It's all done in OpenSCAD, so I can just scale it there rather than anyone having to redesign anything. It took me so long to get the maneuver templates to be mathematically satisfying.
They are all technically the same "length" just bent.

Teque5, 2022-05-11:
Let me noodle on this a bit.

An issue with using the existing octagon move templates is that they would be too wide to fit in the available space. I think I can modify / create new move templates for hexagons that would actually fit.

Wollivan, 2022-05-11:
I mean I can change size of the octogon :)

Wollivan, 2023-05-25:
@Teque5 I loved the work you did on this!

I hope you don't mind me closing this issue as I've now made a printable box that fits everything 4 players need to play!

Closed 2023-05-25.

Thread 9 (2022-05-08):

Remove barrel roll notches from templates

Wollivan, 2022-05-08:
With the new rule making use of the existing 2 and 3 templates, there is now no need for the notches.

They will only be commented out just in case need for such a feature arrises.

Wollivan, 2022-05-09:
This was resolved in Pull Requests #18 and #19.

Closed 2022-05-09.

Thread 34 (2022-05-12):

The range ruler needs to change, PR incoming, please comment!

Wollivan, 2022-05-12:
There are a few reasons why:

1. It adds a lot of scope for further game design, with different bonuses being awards depending on range (like X-Wing TMG)

2. The AI for campaigns needs more info about where the players are to make decisions on movement.

This last point is weaker but worth pointing out

3. The string is great because it fits in the box no matter the size, but it's harder to accurately tie the knots in the right place, so I think it should be marks on a string rather than knots.

I'm going to make a pull request, I will wait 24 hours before pushing, to give people a chance to comment on the changes as it's probably the biggest change to the core game since I made the game public.

Wollivan, 2022-05-12:
Pull request created here, please check it out if you get a chance!

Closed 2022-05-19.

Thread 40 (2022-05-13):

Feature request: base that fits popular plane models from other games

lifelike, 2022-05-13:
I do not know if this is feasible or easy to do, but maybe it is possible to make a base without the airplane on, but with a slot that fits the pins used to hold aircraft in some other popular games that are sold with nice pre-painted airplanes. Worst case maybe just a hole where a pin from that game system can be glued and used to attach a plane. The base could still be stackable on top of the altitude markers and of course fit the movement templates.

lifelike, 2022-05-13:
Actually I am not sure I would want to use this anyway. It just seemed like something that was possible and maybe someone else would enjoy. Please close if it seems like a bad idea.

Wollivan, 2022-05-13:
This is actually already in the files, great minds think alike eh? ;)

There is a blank plane STL model, but at the moment it has no slot.

If you have a game in mind, and know the size of the stand, I can create one specifically and add it to the existing models :)

Wollivan, 2023-05-25:
@lifelike I have finally gotten around to adding an expansion that allows for use of X-Wing TMG pieces.

Did you have any other games in mind that I could create pieces for?

https://squadronleader.wollivan.dev/expansions/x-wing-compatibility

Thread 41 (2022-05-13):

Someone with OctoPrint, could you film a set being printed for the website?

Wollivan, 2022-05-13:
I'd like to put a gif at the top of the page showing the entire set being printed (not necessarily in one go) but I don't have the means to make a nice looking one.

Winehorn, 2022-05-13:
I might have accidentally recorded my print 😁 will check tomorrow

Wollivan, 2022-05-13:
> I might have accidentally recorded my print 😁 will check tomorrow

That is hilarious! Thanks Flo!

Winehorn, 2022-05-13:
Might need to invest in some lighting 😄

Wollivan, 2022-05-13:
Lol!! Very dark video?

Winehorn, 2022-05-13:
Started the print in the evening, so [yeah](https://ibb.co/7v9k1JF) 😄

Wollivan, 2022-05-13:
> Started the print in the evening, so [yeah](https://ibb.co/7v9k1JF) 😄

This is so funny haha!

Winehorn, 2022-05-13:
Camera tired, camera going to sleeeep 😴

I'll maybe do another set this weekend and this time I'll do it in the morning 😉

Wollivan, 2022-05-13:
Only do it if you want to, please don't feel like you have to just for the video!

Winehorn, 2022-05-22:
Printed two stat trackers and the pluggable ruler today, will upload the video tomorrow 😊

Wollivan, 2022-05-22:
> Printed two stat trackers and the pluggable ruler today, will upload the video tomorrow 😊

Thanks so much bro! Excited to see it!

Winehorn, 2022-05-23:
[Here](https://ibb.co/RNQv8GY) you go! Have to work on the quality though. And on a mount for attaching the camera to the z-axis :D

Wollivan, 2022-05-23:
Awesome thanks so much!

I'll get this added to the website tonight :)

Wollivan, 2022-05-31:
Finally got round to adding this so thank you! Closing the issue :)

Wollivan, 2023-05-18:
No longer required, but thank you @Winehorn !

Closed 2023-05-18.

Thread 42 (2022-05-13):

Multi colour pieces

Wollivan, 2022-05-13:
Does anyone have the expertise to make a model specifically for multi colour printers to print planes that have a different colour top?

It's not something I've ever touched so if someone knows and is happy to make the files that would rock!

Winehorn, 2022-05-13:
Not sure how it works for real multicolour printers but at least in PrusaSlicer I can specify a layer where the printer stops and waits for filament change. That should work perfectly with the plane models!

Wollivan, 2022-05-13:
Oh nice! I just remembered I've done exactly that with Cura, can't believe I'd forgotten about that haha

Closed 2022-05-19.

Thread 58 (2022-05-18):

Automate the creation of 2D-printable pieces from the 3D models

penyuan, 2022-05-18:
We started a discussion in pull request #51 about the possibility of deriving 2D-printable files from the 3D models in this repository. This way, someone without access to a 3D printer can print the pieces onto paper (and maybe cardboard) and play the game that way.

A few starting points from that thread for further discussion:

1. [This thread/post](https://graphicdesign.stackexchange.com/a/118521/251) about projecting a 3D CAD file onto a 2D plane then export as SVG.
2. @lifelike said: The script that I used in Inkscape to create the countersheet can run from the command-line as well. It still requires Inkscape to be installed, but at least it can be fully automated. If someone can figure out how to create a SVG (or PNG) from the CAD files it should be possible to set up export of the complete sheets: https://github.com/lifelike/countersheetsextension/wiki/Running-from-Command-Line
3. [OpenSCAD](https://openscad.org) allows scripting (i.e. automating) the projection of 3D models onto 2D images, *and* making 2D slices of 3D models. See [this documentation page](https://en.wikibooks.org/wiki/OpenSCAD_User_Manual/Using_the_2D_Subsystem#3D_to_2D_Projection).
4. Once there is a 2D SVG, I know [Inkscape](https://inkscape.org) can be scripted to do further post-processing as needed.

Does any of the above sound promising? It'll be cool if we can integrate this into a continuous integration pipeline!

lifelike, 2022-05-18:
I think it can work. See the CSV and SVG file already checked in, that would be the input to the script. They can certainly be improved and possibly expanded to include more types of things, but should be enough for testing out the automation already.

Currently the plane used on the 2D counters is part of that template SVG. To make it use a SVG generated from OpenSCAD it should refer to an external file instead. The same thing for every other generated image to include on a counter.

lifelike, 2022-05-18:
I added a quick-and-dirty script in PR #59.

For some reason when including SVG-images inside of the countersheet SVG the lines became a bit wavy and blurry. I exported the plane silhouettes to PNG instead and used those images. I think exporting the OpenSCAD  models to PNG will work better, unless someone can figure out what was wrong with importing SVG. With high enough resolution the results should look good anyway.

Wollivan, 2023-05-25:
I have finally found the feature in OpenSCAD that I was looking for, and can now export SVGs of a projection of the model using `projection()` funnily enough!

Here is the manoeuvre template for example:
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

The only issue is it doesn't notice lines in the image if they don't go all the way through. For example, here is the plane token:
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

Really not much use!

All this means is I need to go through and modify the models to have all the lines be from top to bottom and export the SVG, which is time consuming.
So this will soon be done soon, and there will be an SVG version of every game asset!

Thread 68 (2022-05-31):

Plane identification

lifelike, 2022-05-31:
It would be useful if each plane had some kind of ID letter/digit/number on it and also corresponding IDs on the status boards. Or some system with ID tokens that can be placed somehow to show what plane belongs to what player/board (and type of plane, with the optional plane type status cards that are being discussed).

Wollivan, 2022-05-31:
Yet again looking at X-Wing on how they did it and seeing how we can improve!

I will have a think!

I think this is less of an issue for printed sets, as you can print the plane and stat board in the same colour.

lifelike, 2022-06-01:
I was thinking about the colors, and the photo of the status boards looks amazing, but someone might want to print in only two colors for team play, or/and run out of different colors that they want to use. Or be color-blind. I don't know. Identification seems like a useful thing. For writing things down as well I guess, if some mode ever could use that, rather than trying to describe the color of each plane you want to keep records for.

amnos0405, 2022-06-03:
Hey hey, threw together a quick idea and test print. I know the black is hard to see but I was lazy and didn't want to change filament lol. Let me know your thoughts...

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

Also learned some OpenSCAD and have converted all the stat board pieces into it so it's a bit more collaborative enabled(?).

I'm heading out of town for the weekend but will upload files when I return.

And Tim, I am down for sending you more copies as you asked on Reddit. I'll DM you there.

amnos0405, 2022-06-03:
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

lifelike, 2022-06-06:
That looks great! My only question is if that is a too round peg that allows the little ID token to spin around (that sounds like something that could get annoying)? But maybe it is more square than it looks to me in the photo. Plans for an identical hole in the player board, so that the matching ID token can be attached there?

Looks like more than one digit would be difficult with this method, but if letters are used instead of (or in addition to) digits there will be no risk of running out of different IDs. Guess more than 10 planes per side (or even 10 planes total) will be rare, but it is a fun case to support (and with that many planes having identification becomes even more important).

Letters might be better for IDs since they can not be confused with various ratings, especially if added to the player boards.

amnos0405, 2022-06-07:
New iteration...
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

Wollivan, 2022-06-07:
These are really great ideas guys, I'm once again blown away by.this little community!

Great work on getting everything into OpenSCAD dude, you like it?

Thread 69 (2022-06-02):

Proposal: New modular rule - "Pushing the envelope"

asmialek, 2022-06-02:
The flight envelope is a graph visualizing the capabilities of the aircraft in terms of min-max speeds and the altitude at which it can safely fly. The envelope itself is of course defined by various parameters and there is absolutely no way of simulating that in a board game. But, there is a term ["Pushing the envelope"](https://en.wikipedia.org/wiki/Flight_envelope#%22Pushing_the_envelope%22), which means that the pilot tries to go over the speed or altitude defined by the flight envelope while risking the integrity of the aircraft (or causing the plane to stall).

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

To show this, why not add the ability for the daring pilots to be able to "Push the envelope", giving them the ability to either have 1 more Speed for a round or gain 5th altitude token, at the risk of losing some health?

Say:

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

I'm not married to the exact wording, but it would give a nice "push your luck" element to the game

Wollivan, 2022-06-07:
Ah man I really like the flavour of this rule!

I also like the name, again, because it's so flavourful!

I've had a ridiculously crazy week and a bit, so I've got a bunch of minor rules corrections to add, but this goes to the top of the list to be added!

Wollivan, 2023-05-18:
I totally thought I'd already done this @asmialek !!

Its now in the game as of https://github.com/Wollivan/SquadronLeader/pull/101 <3

Closed 2023-05-18.

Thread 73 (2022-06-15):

Split OpenSCAD files

Wollivan, 2022-06-15:
IT currently has a lot of info all in one file so may benefit from being split into files for each type of component.

Wollivan, 2022-12-31:
All done! Now each asset is in its own named .scad file.

There are now only 4 main .stl files which should make it easier to get into to start with.

Closed 2022-12-31.

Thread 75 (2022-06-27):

Create a separate set of files in SVG format for laser cutting

Molkavi, 2022-06-27:
I plan on printing everything on clear acrylic with a laser cutting machine. It's just "cheaper", faster, and more accurate than 3D printing. The laser-cutting process can also create enough bas relief to accommodate all token functionality.

Transparency on some of the tokens can also enable some pretty cool (untested) UI improvements and mechanics (e.g. stackable altitude tokens, customizable plane look/loadout, etc.)

Can we get the core fileset in SVG format?

Wollivan, 2022-06-27:
This is a great idea! I will have a look at exporting this now!

Wollivan, 2022-06-28:
Having some issues with exporting as SVGs from OpenSCAD.

Its moaning about the objects not being 2D, so if anyone knows a simple way to just flatten them and export I will have a go!

I also want to ask @Molkavi , do they need to be individual SVGs, or can you work from one that is the entire set all in one go? Either is fine!

Molkavi, 2022-06-29:
I should have no problem with a single file, I can always break it down into individual components later.

I'll give 2D'ing it a shot in Blender, I've done that kinda thing before.

Hopefully it'll take.

Molkavi, 2022-06-29:
So I just finished a quick and dirty SVG file set, only the bare necessities, and I can publish it if I get write access.

I think, however, that it'd be much less of a hassle going forward to just have the core file set as a 2D vector design and extrude those 2D designs into 3D pieces as necessary.

After all, most pieces are 2D designs with varying levels of extrusion, right?

Wollivan, 2022-07-03:
Nice one! You should just be able to push to a branch and create a Pull request :)

Also good thought about the models. Once we have a definite set of unchanging models I will make this how it works!

Molkavi, 2022-07-05:
I tried, says I don't have write access to the repo =(

On another note, if I can get some measurements for the pieces I feel pretty confident I can do the SVG templates in Illustrator.

Wollivan, 2022-11-01:
Sorry I never did this @Molkavi, I will get this sorted in the next week!

Molkavi, 2022-11-02:
No problem mate, just let me know so I can contribute, all the best!

Wollivan, 2022-12-30:
@Molkavi I'm actively working on this again, so if you can DM me an address, I can send you. A copy, and you can measure the pieces, and have a reference. For the measurements at the moment, I'm working on changing the way the OpenSCAD files are organised, so there is/will be (depending on when you read this) a file called variables which will have all the measurements in mm in.

Wollivan, 2022-12-30:
@Molkavi I'm actively working on this again, so if you can DM me an address, I can send you. A copy, and you can measure the pieces, and have a reference. For the measurements at the moment, I'm working on changing the way the OpenSCAD files are organised, so there is/will be (depending on when you read this) a file called variables which will have all the measurements in mm in.

Molkavi, 2023-01-03:
Yeah, I was thinking of redoing all the templates on Blender using mm scale, in 2D, and then just have a separate file for 3D printers which is basically the original file with a couple mm of extrusion.

Wollivan, 2023-02-03:
Hi Molkavi, I realised why it might not be working!

Did you fork the repo first?

If you fork it, make the changes on the fork, then when you're done go to pull requests (again on your own repo)

Hope that helps!

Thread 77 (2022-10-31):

Create simple manuever diagrams

Wollivan, 2022-10-31:
Hey @asmialek!

is there any chance you could create some diagrams in the same way you did for the Barrel roll/Split S, but for the default manuevers?

<3

Wollivan, 2023-01-18:
@asmialek can I ask a few additional favours?

1. Could you remake all the images with the new maneuver template? (the one with all 3)
2. Do you know how to get all the pieces as some sort of image? If yes could you give them to @lifelike in this issue: https://github.com/Wollivan/SquadronLeader/issues/58
3. Could you make the wording for each image as follows (there has been some rules changes):

### Normal Maneuver
No text

### Split S
Costs 4 altitude in addition to the normal maneuver cost

### Immelmann
Optional maneuver after a knock out. Gain 3 altitude and turn 180° at end of maneuver

### Barrel Roll
Costs 1 additional maneueverability

For barrel roll, could you also make one that says "2" instead of "1", as the rule is in flux!

Sorry to ask so much of you!!

Wollivan, 2023-05-25:
Hey! If you are still up for doing these diagrams (to which there is actually no pressure) the rules have been refined a little since we last spoke, and a few more manoeuvres have been added.

All the details of what they do can be quickly found here:
https://squadronleader.wollivan.dev/rules/quick

Or in more detail:
https://squadronleader.wollivan.dev/rules/advanced-manoeuvres

asmialek, 2023-05-29:
Hey @Wollivan. Sorry it took so long 😉

I am not sure where the website source code is located, so I'm leaving this up to you to place the files where they should be. Here is the folder with all the new, fixed and "upgraded" images: [GDrive link](https://drive.google.com/drive/folders/1uKSwLi3raS9jny5_hUE5lJqNOt7kXsJb?usp=drive_link)

I'm also sharing my `.svg` work file, in case I'm unavailable again.

Let me know if anything is missing - I couldn't visualize "Pushing the Envelope" nicely, so if you have any ideas I can quickly make something.

Should I also do some diagrams of attacking/defending?

asmialek, 2023-05-29:
Oh man, I just saw the reuqest for the new maneuver template - I'll fix that in the following days, shouldn't be that time-consuming.

asmialek, 2023-05-29:
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
Does it look ok to you?

Wollivan, 2023-05-29:
> 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
> Does it look ok to you?

Oh man this is sick!

Wollivan, 2023-05-29:
If you're happy to do attacking defending (range and 90° arc and forward arc) would be really cool.

Another request, how easy would it be to change the colours in this diagrams?
I'm trying to unify the colour branding of the game, and have found some colours I really like

Wollivan, 2023-05-29:
Also, please don't apologise, you're doing something so sick and I love it!

Wollivan, 2023-05-29:
Sorry for the shower of comments!

Regarding the location of the website, it's all.driven from the markdown files in this repo, so feel free to make a PR with both the images added to a folder, and added to the advanced_manoeuvres.md

Regarding the colours, I am going to try and get some hex codes together tomorrow!

asmialek, 2023-05-30:
> Another request, how easy would it be to change the colours in this diagrams?

It should be as easy as doing `Find and Replace` in the SVG file.

Wollivan, 2023-05-30:
@asmialek here is an SVG of the new manoeuvre:

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

Wollivan, 2023-05-30:
And here are the colours I'm thinking will be the main "brand" colours:

blue: #16c2d9
green: #1cad43
yellow: #fffb4a
orange: #f8903a

Any of the game pieces can be any of these colours.

Would it be possible to make one final request:
When you make the versions with the new manoeuvre tempalte, could you make them all SVGs incase the the colours change so I can quickly edit them?

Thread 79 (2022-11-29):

Dive bomb rule

Wollivan, 2022-11-29:
Working idea:

During the attack stage, if you are within range 1 of the defending plane, and have 2 or more altitude than defending plane, you can lose 2 altitude to add an attack dice to your roll.

Wollivan, 2023-02-08:
Reading about dive bombing I think this manoeuvre should come with risk, as you are flying directly at the enemy plane.

To that end, a new proposed rule that I will add to the advanced rules, with a. view for more playtesting:

After a players has attacked, if the defender is within range one **and** the attacker has at least 2 more altitude than the defender, they may attempt to perform a dive bomb manoeuvre:

- Remove altitude tokens from the attacker until they have the same number as the defender
- The attacker rolls a d6:
  - On a 2-6 result the defender suffers 1 damage
  - On a 1 result the attacker suffers 1 damage

You can read more about the Dive Bomb manoeuvre here:

<a href="https://en.wikipedia.org/wiki/Dive_bomber" target="_blank" class="button">Immelmann Wiki</a>

Here is an excerpt:
"A dive bomber is a bomber aircraft that dives directly at its targets in order to provide greater accuracy for the bomb it drops. Diving towards the target simplifies the bomb's trajectory and allows the pilot to keep visual contact throughout the bomb run."

Not to be confused with the Divebomb, the homicidal Decepticon.

Closed 2023-02-08.

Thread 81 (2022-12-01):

Alternative to clips on stat board, for people with flimsy plastic

Wollivan, 2022-12-01:
Instead of the clipping on the bar, they will slot into a spot, which changes how many pieces can break.

Wollivan, 2022-12-10:
I have changed this now

Closed 2022-12-10.

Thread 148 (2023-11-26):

Make a version of player pieces + stat wheel printable under 3m of fillament.

Level0gamedev, 2023-11-26:
I like the new stat wheel approach and having player pieces and the wheel rings the same color. Makes me want to print bunch of different colors, but that can get pretty pricey to get bunch of even small (250g) spools of filament. However, you can buy "color samplers" pretty cheap online that give you 10 feet (so around 3m) chunks of different colors.

To print the player.stl and stat_wheels.stl (with a skirt) at .2mm layer height you currently need 3.77m according to Cura. It would be cool if we could get a version that would print under 3m so it would be cheaper for people to print bunch of play pieces.

Maybe the stat wheel could be tweaked in size/thickness/whatever to achieve that?

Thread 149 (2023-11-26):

Add optional Critical Hit rules

Level0gamedev, 2023-11-26:
**Optional Rule - It hit something important!:  When you suffer a critical hit, the second point of damage is dealt to one of the remaining stats, decided randomly. If any stat reaches 0, you crash**

WW1 planes were prone to mishaps. Guns skipping or jamming, wires catching on something or the yoke getting stuck were not uncommon. Many of them were just mechanical faults, but many would also be a side-effect of something more crucial being hit during combat. This rule is a nod to all those things.

If the "death spiral" is an issue, we can always add another optional rule where a player can recover some lost stat points with something like this:

**Optional Rule - Quick Fix!: Once per round spend any amount of available maneuverability points. For each point spent, roll a d6. If you rolled at least one 4-6 you can recover one of your lost stat points**

Apart from helping with the death spiral, this rule gives players more choice during the game, as now instead of always trying to shoot the enemy down, you have an option to run away and try to come back. It's also pretty true to actual WW1 air combat, when pilots would try to break away from the "hornets' nest" to fix a jammed gun with a hammer or untangle a wire stopping you from turning left, etc. Using maneuverability points because at this time you're not really flying the plane, your doing the fixing and letting the plane just go on its own, maybe keeping the yoke between your legs to go more or less straight ;)

Wollivan, 2025-03-10:
@Level0gamedev  I'm a bit late to the party but I LOVE this idea! This is a huge flavour win and super fun!

Will do some testing on it hopefully this week :)

Wollivan, 2025-03-11:
So we played this, and it seems WAY more balanced.

I think I'm gonna change the main rule to this, with a caveat of cancelling non 6's first, and then an optional rule is fixing the damage, which needs to follow the tenets of simple but flavourful, so more testing to be done!

Thanks for the idea, it's just brilliant!

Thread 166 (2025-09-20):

A Better Box

Teque5, 2025-09-20:
In the process of making a dozen of these for my club I made a secure compact box where the parts cannot get loose or disorganized.

Currently [the design is on printables](https://www.printables.com/model/1419548-squadron-leader-compact) but I can create a PR here if you like.

The version in the photos is for 12mm Dice, but I created versions for both standard  (16mm) and mini (12mm) dice.

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

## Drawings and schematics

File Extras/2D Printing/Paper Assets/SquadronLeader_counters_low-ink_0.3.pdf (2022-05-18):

## SQUADRON LEADER OPTIONAL COUNTERS 1/1 v 0.3

1

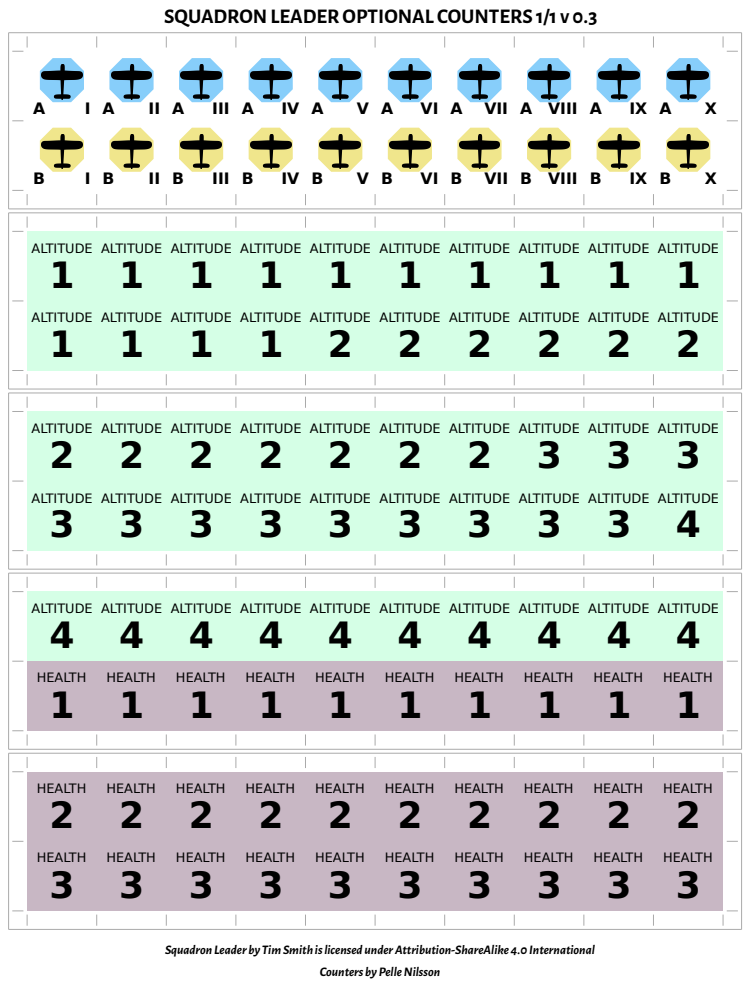
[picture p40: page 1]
III A; VI A VII A VIII A; III B; VI B VII B VIII B; ALTITUDE; HEALTH

Squadron Leader by Tim Smith is licensed under Attribution-ShareAlike 4.0 International

Counters by Pelle Nilsson

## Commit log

2022-01-27 Change file names to be more descriptive and add readme with priting instructions and game rules
    [move_.stl, move_bank.stl, move_turn.stl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]
2022-01-27 Add arc to plane token and update rules
    [player_plane.stl, player_plane_blank.stl, playerpieces.scad]
2022-01-30 Use cos and sin to calculate curve piece. Add numbers to move templates
    [move_.stl, move_bank.stl, move_straight.stl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]
2022-02-18 Rules update and token teak
    [playerpieces.scad]
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2022-02-21 Add forward arc to token
    [playerpieces.scad]
2022-02-21 Add front arc to STLs
    [player_plane.stl, player_plane_blank.stl]
2022-04-21 These are not the commits you are looking for
    [move_bank.stl, move_straight.stl, move_turn.stl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]
2022-04-21 Change link from download to github links
    [move_bank.stl, move_straight.stl, move_turn.stl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]
2022-04-21 Added actual files to project, this is now the only aeronauts repo
    [move_bank.stl, move_straight.stl, move_turn.stl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]
2022-05-03 Host images on GutHub and remove hidden images
    [playerpieces.scad]
2022-05-03 Fix button styles
2022-05-03 Make numbers in templates completely holo
    [playerpieces.scad]
2022-05-03 Add barrel role rules, and adjust measurements for barrel role notches to be exactly 1 apart
    [playerpieces.scad]
2022-05-03 Fix button margins
2022-05-05 Push new straight tempalte
    [move_straight.stl]
2022-05-05 Add single maneuver template
    [move_all.stl, playerpieces.scad]
2022-05-06 Increased holes underneath pieces for ease of use
    [player_altitude.stl, player_plane.stl, playerpieces.scad]
2022-05-06 Moved outputs in scad file to top. Added objective
    [playerpieces.scad]
2022-05-06 Fixed printing instructions
2022-05-06 Correct bank and turn STLs. Add email to footer
    [move_bank.stl, move_turn.stl]
2022-05-07 Updated single maneuver template to include a plane icon at start
    [move_all.stl, playerpieces.scad]
2022-05-08 Fixed barrel roll notches on the single maneuver template
    [move_all.stl, playerpieces.scad]
2022-05-08 Remove notches from the templates and recreate STLs
    [move_all.stl, move_straight.stl, playerpieces.scad]
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2022-05-09 Add scad and stl file for printable box
    [box.scad, box.stl]
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2022-05-12 Create printable range rulers. Bendy and not
    [playerpieces.scad, range_bendable.stl, range_solid.stl]
2022-05-15 A fancy top proposal that matches the tobacco tin
    This consists of two parts, the first a topper to glue on that features parts of the tobacco tin design. The topper is 'divided' into 5 levels to be able to be able to perform filament swaps of different colors. The bottom level of the topper is 6mm giving 3, 2mm layer height passes. All other levels are 4mm allowing 2, 2mm layer height passes. The second part is a new top that still fits the box bottom, but has corner bevels that match the topper.
    [SquandronLeader_FancyTop.stl]
2022-05-15 Remove bendable ruler. Add marks to solid ruler and change naming. Signed off by Tim Smith tim.smith2814@gmail.com
    [playerpieces.scad, range_bendable.stl, range_ruler.stl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]
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2022-05-16 Optional countersheet for playing without 3D printer
    Countersheet is made using Inkscape and the Countersheetsextension
    (see https://github.com/lifelike/countersheetsextension/).
    Generated PDF included.
    [low-ink.csv]
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2022-05-16 Moved fancy top/topper into STL folder
    [SquandronLeader_FancyTop.stl]
2022-05-16 Delete SquandronLeader_FancyTop.stl
    Moved to STL folder
    [SquandronLeader_FancyTop.stl]
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2022-05-17 Add initial stls for stat tracker
    Glad to hear ideas and feedback on these. Left both numbers and dots as options.
    [statBoard.stl, statChitsDots.stl, statChitsNumbers.stl]
2022-05-18 2D countersheet with automation
    Added automation script make_countersheet.sh.
    Added PNG-version of plane-model, because using
    the SVG in the countersheet did not look good
    for some reason.
    Also fixed the size on counters that was off and
    replaced the altitude and health markers with
    more useful versions.
    With the plane-models as external images it is
    no longer possible to set the colors using
    the countersheetsextension the way it was
    done in the previous versions. That is why
    the background octagon was added to the
    counters.
    [counters.csv]
2022-05-19 Improved stat tracker
    When playtesting the initial design everything shifted around at every little table bump or shaky hand. I've added in a snapping ability for the stat chits into the border. Also changed the loosey goosey health triangle to a peg/hole for more stability and a cleaner look.
    [statBoard.stl, statChitsDots.stl, statChitsNumbers.stl]
2022-05-19 Split box into bottom and top part
    [box.stl, box_top.stl]
2022-05-19 Added fully cutout number chits
    [statChitsNumbersCutout.stl]
2022-05-19 Add interlocking range ruler
    [BridleJoint.scad, DovetailJoint.scad, DowelJoint.scad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]
2022-06-10 Add parameter for statBoard ID toggle
    [playerpieces.scad]
2022-06-10 Added OpenSCAD generated STLs and new ID STLs
    The old stat chits and stat boards should fit with the new ones, but just in case I replaced the old boards and chits to make everything from the same source (openSCAD).
    [IDChits_A_E.stl, player_plane_wID.stl, statBoard.stl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]
2022-06-10 Moved new files into proper STL folder...
    ...because I was initially a goob
    [IDChits_A_E.stl, player_plane_wID.stl, statBoard.stl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]
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2022-06-28 Neatened up the folder structure to make the printable assets easier to find
    [BridleJoint.scad, DovetailJoint.scad, DowelJoint.scad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]
2022-12-10 Seperate assets in OPENScad
    [bomber.scad, modules.scad, move_templates.scad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]
2022-12-10 Make stat board less fragile
    [stat_board.scad, variables.scad]
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2022-12-31 Correct printing instructions
2022-12-31 Separate readme into relevant file names
    [tokens.scad]
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2022-12-31 neaten rules and make template sexy
    [move_template.stl]
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2023-01-06 Speed to Maneuverability. Guide lines
    [maneuver_bank.stl, maneuver_straight.stl, maneuver_template.scad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]
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2023-01-25 Fix issue with arrows on single template
    [maneuver_template.scad]
2023-02-08 Change spelling to original french
    [maneuver_template.scad, output.scad, stat_board.scad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]
2023-05-09 Create box for 4 players only
    [box.scad, box.stl, box_top.stl]
2023-05-09 Box size fix
    [box.scad, box.stl, box_top.stl]
2023-05-10 Change dovetail joint to simple joint
    [range_ruler.scad, range_ruler.stl, range_ruler_1_only.stl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]
2023-05-10 Create version 1 of insert
    [box.scad, box.stl, box_test.scad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]
2023-05-10 Actually add the insert STL to the files
    [box.scad, insert.stl]
2023-05-11 Ruler tolerances
    [range_ruler.scad, range_ruler.stl]
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2023-05-18 Change tolerances of models
    [box.scad, box_top.stl, range_ruler.scad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]
2023-05-18 Create new stat board that fits in small box
    [new_stat_board.scad, stat_board.stl]
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2023-05-19 Create life counter on board and adjust box size
    [box.scad, box.stl, box_base.stl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]
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2023-05-25 Fix spelling on manoeuvre file
    [manoeuvre_template.scad]
2023-05-31 Change folder structure to bring 3d to fore. Add reference images
    [bombers_and_balloons.scad, box.scad, box.stl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]
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2023-06-01 Make it easier to get health chit out
    [stat_board.scad, stat_board.stl, stats_board_only.stl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]
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2023-06-07 Fix no holes on xwing
    [plane_xwing_tmg.stl, xwing_compatible.scad]
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2023-06-24 Fix size issues with box
    [box.scad, box.stl, box_base.stl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]
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2023-09-24 Correct orientation of rules print
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2025-01-22 Flip rules text in lid and create basic stat board
    [basic_stat_board.scad, basic_stat_board.stl, box.scad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]
2025-02-05 Add basic stats that fit in small box
    [2334.stl, 2343.stl, 2433.stl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]
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2025-10-05 Add new but actually old version of stat board
    [stat_board_w_health.scad, stat_board_w_health.stl]

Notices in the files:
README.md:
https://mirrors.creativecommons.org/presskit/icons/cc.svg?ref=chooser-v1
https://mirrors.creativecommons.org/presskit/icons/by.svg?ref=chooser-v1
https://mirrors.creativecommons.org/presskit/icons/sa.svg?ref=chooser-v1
